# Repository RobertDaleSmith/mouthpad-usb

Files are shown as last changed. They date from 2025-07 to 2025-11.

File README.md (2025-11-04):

# MouthPad^USB

Firmware for turning the **MouthPad^** wearable into a wired USB HID device. The microcontroller sits between the tablet/PC and the MouthPad^, bridging BLE HID + NUS traffic to USB HID + CDC, without changing the MouthPad^ firmware.

## Overview

This repository contains **two platform implementations** that expose identical USB interfaces:

| Platform | MCU / SDK | Status | Documentation |
|---|---|---|---|
| **Nordic nRF52840** | NCS / Zephyr RTOS | ✅ Production | [ncs/README.md](ncs/README.md) |
| **ESP32-S3** | ESP-IDF | ✅ Feature parity | [esp/README.md](esp/README.md) |

Both firmwares expose the same HID descriptors, CDC command set, LED semantics, and bond-management behavior, so you can swap hardware without reconfiguring the host.

## Quick Start

Pick the platform that matches your hardware:

### nRF52840 (Production Hardware)

Ships on **Seeed XIAO nRF52840**. Also supports Adafruit Feather nRF52840 and Nordic/April dongles.

```bash
cd ncs
docker-compose run --rm mouthpad-build
# Flash: drag build/app/zephyr/zephyr.uf2 to bootloader drive
```

**[👉 Full NCS documentation](ncs/README.md)**

### ESP32-S3

Alternative implementation for **Seeed XIAO ESP32-S3** and LilyGo T-Dongle-S3.

```bash
cd esp
source env.sh          # Source ESP-IDF environment
make xiao              # Build for XIAO ESP32-S3
make flash             # Flash firmware
```

**[👉 Full ESP32 documentation](esp/README.md)**

## Core Features

### USB Interfaces

- **USB HID** – Mouse + consumer control (standard multi-interface HID device)
- **USB CDC Port 0** – Protobuf/text tunnel mirroring BLE NUS link
- **USB CDC Port 1** – Maintenance console (`dfu`, `clear`, `serial`) + logs

### BLE Bridge

- **BLE HID client** – Discovers and connects to MouthPad^ HID service
- **Nordic UART Service (NUS)** – Bidirectional data tunnel for configuration/telemetry
- **Bond management** – Stores pairing and auto-reconnects
- **RSSI monitoring** – Tracks connection quality

### Status Feedback

- **LED indicators** – Scanning (blink), connected (solid), activity (flicker)
- **NeoPixel support** (nRF) – Battery-level colors when available
- **Console logging** – Real-time diagnostics on CDC port 1

### Device Firmware Update (DFU)

| Platform | Method |
|---|---|
| nRF52840 (UF2) | UF2 bootloader (drag-and-drop) or type `dfu` command |
| nRF52840 (Nordic DFU) | Nordic DFU bootloader via nrfutil or nRF Connect Desktop |
| ESP32-S3 | ROM serial downloader via `dfu` command or `idf.py flash` |

## Repository Structure

```
.
├── ncs/                    # Nordic Connect SDK workspace (nRF52840)
│   ├── app/                # Application source
│   ├── Makefile            # Build helpers
│   ├── docker-compose.yml  # Containerized builds
│   └── README.md           # 👈 nRF52840 documentation
├── esp/                    # ESP-IDF workspace (ESP32-S3)
│   ├── main/               # Application source
│   ├── Makefile            # Build helpers
│   └── README.md           # 👈 ESP32-S3 documentation
├── resources/              # Additional documentation and assets
│   ├── notes/              # Technical documentation
│   └── images/             # Diagrams and photos
└── web/                    # Web-based configuration tool
```

## CDC Maintenance Commands

Both firmwares expose a maintenance console on the second CDC port:

| Command | Description |
|---|---|
| `dfu` | Reboot into bootloader (UF2 for nRF, ROM downloader for ESP32) |
| `reset` | Disconnect MouthPad^, erase BLE bonds, return to pairing mode |
| `restart` | Restart firmware (software reset) |
| `serial` | Print USB serial number |
| `version` | Display firmware version, build timestamp, and platform info |

**Port names:**
- **macOS:** `/dev/cu.usbmodem<serial>3`
- **Linux:** `/dev/ttyACM1`
- **Windows:** `COM<n>` (check Device Manager)

## Supported Hardware

### nRF52840 Boards

| Board | Status | Notes | Purchase |
|---|---|---|---|
| Seeed XIAO nRF52840 | ✅ Production | Primary shipping target ([expansion board](https://www.seeedstudio.com/Seeeduino-XIAO-Expansion-board-p-4746.html) supported) | [Seeed Studio](https://www.seeedstudio.com/Seeed-XIAO-BLE-nRF52840-p-5201.html) |
| Adafruit Feather nRF52840 Express | ✅ Production | Requires custom bootloader config | [Adafruit](https://www.adafruit.com/product/4062) |
| Nordic nRF52840 Dongle (PCA10059) | ✅ Production | Stock Nordic LED pins | [Digi-Key](https://www.digikey.com/en/products/detail/nordic-semiconductor-asa/NRF52840-DONGLE/9491124) |
| April Brothers nRF52840 Dongle (PCA10059) | ✅ Production | Non-standard LED wiring | [April Brother](https://store.aprbrother.com/product/usb-dongle-nrf52840) |
| Raytac MDBT50Q-RX Dongle | ✅ Production | UF2 bootloader, single LED | [Raytac](https://www.raytac.com/product/ins.php?index_id=89) |
| Raytac MDBT50Q-CX-40 Dongle | ✅ Production | Nordic DFU bootloader, blue+red LEDs | [Raytac](https://www.raytac.com/product/ins.php?index_id=100) |
| MakerDiary nRF52840 MDK USB Dongle | ✅ Production | RGB LED support | [MakerDiary](https://wiki.makerdiary.com/nrf52840-mdk-usb-dongle/purchase/) |

### ESP32-S3 Boards

| Board | Status | Notes | Purchase |
|---|---|---|---|
| Seeed XIAO ESP32-S3 | ✅ Supported | Mirrors nRF feature set | [Seeed Studio](https://www.seeedstudio.com/XIAO-ESP32S3-p-5627.html) |
| LilyGo T-Dongle-S3 | ✅ Supported | Alternative form factor | [Amazon](https://www.amazon.com/dp/B0BF542H39) |

## CI/CD

GitHub Actions builds firmware for all board variants on every push to `main`:

**nRF52840 builds:**
- `mouthpad^usb_seeed_xiao_nrf52840_<commit>.uf2`
- `mouthpad^usb_adafruit_feather_nrf52840_<commit>.uf2`
- `mouthpad^usb_nordic_nrf52840dongle_<commit>.uf2`
- `mouthpad^usb_aprbrother_nrf52840_<commit>.uf2`
- `mouthpad^usb_raytac_mdbt50q_rx_<commit>.uf2`
- `mouthpad^usb_raytac_mdbt50q_cx_40_<commit>.zip` (Nordic DFU)
- `mouthpad^usb_makerdiary_nrf52840mdk_<commit>.uf2`

Artifacts are available in the Actions tab for 90 days.

## Contributing

1. **Choose your platform** – Work in either `ncs/` or `esp/` directory
2. **Follow build instructions** – See platform-specific README
3. **Test on hardware** – Verify USB enumeration and BLE connection
4. **Submit PR** – Include board(s) tested in description

Both platforms should maintain behavioral parity for USB/BLE interfaces.

## Getting Help

- **Platform-specific issues:** See [ncs/README.md](ncs/README.md) or [esp/README.md](esp/README.md)
- **General questions:** Open an issue with reproduction steps
- **Build problems:** Check platform-specific troubleshooting sections

## License

MIT License – See [LICENSE](LICENSE) for details.

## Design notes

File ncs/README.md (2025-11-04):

# MouthPad^ USB – Nordic Connect SDK (nRF52840)

This directory contains the **nRF52840 firmware** for the MouthPad^ USB bridge, built with Nordic Connect SDK (NCS) and Zephyr RTOS.

## Overview

The nRF52840 firmware is the **primary production firmware** that ships on Seeed XIAO nRF52840 hardware. It bridges BLE HID + NUS traffic from the MouthPad^ wearable to USB HID + dual CDC interfaces.

**Key features:**
- BLE HID client + Nordic UART Service (NUS)
- USB HID device (mouse + consumer control)
- Dual USB CDC ports (NUS tunnel + maintenance console)
- Bond management and pairing support
- UF2 bootloader support (most boards) or Nordic DFU bootloader (CX-40)
- LED status feedback
- Console commands: `dfu`, `clear`, `serial`

## Supported Hardware

| Board | Status | Notes | Purchase |
|---|---|---|---|
| **Seeed XIAO nRF52840** (`seeed_xiao_nrf52840`) | ✅ Production | Primary shipping target ([expansion board](https://www.seeedstudio.com/Seeeduino-XIAO-Expansion-board-p-4746.html) supported) | [Seeed Studio](https://www.seeedstudio.com/Seeed-XIAO-BLE-nRF52840-p-5201.html) |
| **Adafruit Feather nRF52840** (`adafruit_feather_nrf52840`) | ✅ Production | Requires custom bootloader config | [Adafruit](https://www.adafruit.com/product/4062) |
| **Nordic nRF52840 Dongle** (`nordic_nrf52840dongle`) | ✅ Production | PCA10059 with stock Nordic LED pins | [Digi-Key](https://www.digikey.com/en/products/detail/nordic-semiconductor-asa/NRF52840-DONGLE/9491124) |
| **April Brother nRF52840 Dongle** (`aprbrother_nrf52840`) | ✅ Production | PCA10059 with non-standard LED wiring | [April Brother](https://store.aprbrother.com/product/usb-dongle-nrf52840) |
| **Raytac MDBT50Q-RX Dongle** (`raytac_mdbt50q_rx`) | ✅ Production | UF2 bootloader, single LED | [Raytac](https://www.raytac.com/product/ins.php?index_id=89) |
| **Raytac MDBT50Q-CX-40 Dongle** (`raytac_mdbt50q_cx_40`) | ✅ Production | Nordic DFU bootloader, blue+red LEDs | [Raytac](https://www.raytac.com/product/ins.php?index_id=100) |
| **MakerDiary nRF52840 MDK USB Dongle** (`makerdiary_nrf52840mdk`) | ✅ Production | Compact dongle with RGB LED | [MakerDiary](https://wiki.makerdiary.com/nrf52840-mdk-usb-dongle/purchase/) |

## Quick Start

### Docker Build (Recommended)

```bash
cd ncs
docker-compose run --rm mouthpad-build
```

The build produces `build/app/zephyr/zephyr.uf2` ready for drag-and-drop flashing.

### Native Build (with local NCS toolchain)

```bash
cd ncs

# First time: initialize workspace
make init

# Build for default board (xiao_ble)
make build

# Flash via UF2 bootloader
make flash-uf2

# Or flash via J-Link
make flash
```

**Board-specific builds:**
```bash
make build-xiao              # Seeed XIAO nRF52840
make build-feather           # Adafruit Feather nRF52840
make build-nordic-dongle     # Nordic PCA10059 (stock pins)
make build-april-dongle      # April Brother (non-standard LED)
make build-raytac-rx         # Raytac MDBT50Q-RX (UF2)
make build-raytac-cx40       # Raytac MDBT50Q-CX-40 (Nordic DFU)
make build-makerdiary-dongle # MakerDiary nRF52840 MDK (RGB LED)
```

See the [Makefile](Makefile) for all available targets.

## Workspace Structure

```
ncs/
├── app/                    # Application source and board configs
│   ├── src/                # C source files
│   ├── boards/             # Board-specific overlays
│   ├── prj.conf            # Project Kconfig
│   └── README.md           # Detailed app documentation
├── Makefile                # Build helpers
├── west.yml                # West manifest (NCS dependencies)
├── docker-compose.yml      # Containerized builds
├── Dockerfile              # Build container definition
└── bootloaders/            # Pre-built UF2 bootloaders

# Generated by `make init` or `west update`:
├── .west/                  # West workspace metadata
├── nrf/                    # NCS SDK
├── zephyr/                 # Zephyr RTOS
├── nrfxlib/                # Nordic libraries
├── modules/                # Zephyr modules
└── build/                  # Build output
```

**Note:** The generated directories (`.west/`, `nrf/`, `zephyr/`, etc.) are ignored by git and managed by the `west` tool.

## Detailed Documentation

- **[app/README.md](app/README.md)** – Application architecture, build instructions, CDC commands, LED states
- **[Makefile](Makefile)** – Build targets and helper commands
- **[docker-compose.yml](docker-compose.yml)** – Docker build configuration
- **[../resources/notes/BUILD_METHODS.md](../resources/notes/BUILD_METHODS.md)** – Alternative Zephyr build flows
- **[../resources/notes/ADAFRUIT_FEATHER_BOOTLOADER.md](../resources/notes/ADAFRUIT_FEATHER_BOOTLOADER.md)** – Feather bootloader setup

## Flashing Firmware

### UF2 Method (Recommended)

1. **Enter bootloader mode:**
   - Double-tap the reset button
   - Or type `dfu` in the maintenance console

2. **Copy firmware:**
   - Drag `build/app/zephyr/zephyr.uf2` to the bootloader drive
   - **XIAO:** `/Volumes/XIAO-SENSE` (macOS) or `/media/XIAO-SENSE` (Linux)
   - **Feather:** `/Volumes/FTHR840BOOT` (macOS) or `/media/FTHR840BOOT` (Linux)
   - **Nordic Dongle:** `/Volumes/NRF52BOOT` (macOS) or `/media/NRF52BOOT` (Linux)
   - **Raytac Dongle:** `/Volumes/MDBT50QBOOT` (macOS) or `/media/MDBT50QBOOT` (Linux)
   - **MakerDiary Dongle:** `/Volumes/UF2BOOT` (macOS) or `/media/UF2BOOT` (Linux)

3. **Automatic reboot:** Device resets automatically after copy completes

### J-Link Method

```bash
make flash
```

Requires J-Link probe connected and J-Link software installed.

### Nordic DFU Method (CX-40 only)

The Raytac CX-40 uses Nordic's DFU bootloader instead of UF2. You can flash it via command line or GUI:

**Command Line (nrfutil):**
```bash
# Build firmware first
make build-raytac-cx40

# Flash via DFU (prompts for bootloader mode)
make flash-dfu
```

**GUI (nRF Connect for Desktop - Recommended):**
1. Download [nRF Connect for Desktop](https://www.nordicsemi.com/Products/Development-tools/nRF-Connect-for-Desktop)
2. Install the "Programmer" app
3. Put device in bootloader mode (hold RESET while connecting USB)
4. Select device in nRF Connect Programmer
5. Add the `.zip` file from `build/app/zephyr/` (after running `make flash-dfu` to generate it)
6. Click "Write" to flash firmware

The device will automatically reboot with the new firmware.

## CDC Maintenance Console

The second CDC port (`/dev/cu.usbmodem<serial>3` on macOS, `/dev/ttyACM1` on Linux) provides a maintenance console with these commands:

| Command | Description |
|---|---|
| `dfu` | Reboot into UF2 bootloader |
| `clear` | Clear BLE bonds and return to pairing mode |
| `serial` | Print USB serial number used in device names |

## LED States

| State | Behavior |
|---|---|
| **Scanning** | Slow blink (seeking MouthPad^) |
| **Connected** | Solid on |
| **Activity** | Fast flicker when forwarding HID data |

NeoPixel LEDs (if available) show battery-dependent colors when connected.

## Development

### Prerequisites

- **Docker:** For containerized builds (no local toolchain needed)
- **OR Native:** NCS v3.1.0+ with Zephyr SDK and `west` on PATH

### Build System

- **`make`** – High-level wrapper around `west build`
- **`west`** – Nordic's meta-tool for managing NCS workspace
- **Docker** – Isolated builds with pre-configured toolchain

Run `make help` for all available targets.

### Debugging

**RTT Console:**
```bash
make monitor
```

Or use Segger RTT Viewer for better experience.

**GDB:**
```bash
west debug
```

Requires J-Link probe connected.

## CI/CD

GitHub Actions builds all board variants on every push:
- Seeed XIAO nRF52840
- Adafruit Feather nRF52840
- Nordic nRF52840 Dongle
- April Brother nRF52840 Dongle
- Raytac MDBT50Q-RX Dongle
- Raytac MDBT50Q-CX-40 Dongle
- MakerDiary nRF52840 MDK USB Dongle

Artifacts are uploaded as:
- `mp_usb_<board>_<commit>.uf2` for UF2 bootloader boards
- `mp_usb_<board>_<commit>.zip` for Nordic DFU bootloader boards (CX-40)

See [`.github/workflows/ci.yml`](../.github/workflows/ci.yml) for the full workflow.

## Troubleshooting

**Build fails:**
- Ensure workspace is initialized: `make init`
- Clean and rebuild: `make clean && make build`

**Flash fails:**
- Check bootloader is mounted
- Verify UF2 file exists: `ls -l build/app/zephyr/zephyr.uf2`

**Device not detected:**
- Check USB cable supports data (not just charging)
- Try different USB port
- Check system logs: `dmesg` (Linux) or Console.app (macOS)

**BLE connection fails:**
- Clear bonds: type `clear` in maintenance console
- Restart MouthPad^ wearable
- Check LED is blinking (scanning mode)

For more help, see [app/README.md](app/README.md) or open an issue.

## License

MIT License – See [../LICENSE](../LICENSE) for details.

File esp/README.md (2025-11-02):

# MouthPad^ USB – ESP32 Firmware (ESP-IDF)

ESP-IDF port of the MouthPad^ USB bridge for ESP32-S3 boards. Functionally mirrors the Zephyr/nRF
firmware with 1:1 feature parity: it scans for the MouthPad^ over BLE, relays HID and NUS traffic to USB,
exposes the same dual CDC interfaces, and offers the same maintenance commands.

## Target hardware

* **Seeed Studio XIAO ESP32-S3** – validated board with user button and LED on GPIO 21.
* **LilyGo T-Display-S3** – buildable but the board lacks a dedicated user LED; the firmware disables LED
  status on that variant.

Select the board via `make xiao` or `make lilygo` (defaults to XIAO). The Makefile injects board-specific
`sdkconfig` fragments so switching targets does not leave stale settings behind.

### External antenna setup (XIAO ESP32-S3)

For improved BLE range, use the **XIAO ESP32-S3 Sense** variant with external antenna connector:

**Required components:**
- [8dBi WiFi RP-SMA antenna (2.4GHz/5.8GHz dual band)](https://www.amazon.com/dp/B07R21LN5P) with U.FL/IPEX to RP-SMA pigtail cable
- [3D printable case for XIAO + SMA antenna](https://www.printables.com/model/1367918-xiao-esp32-sma-antenna-case)

The external antenna provides significantly better range than the PCB antenna, especially useful for extended distance operation or through obstacles.

## Features

**Core functionality (matches nRF firmware 1:1):**
* Bridges BLE HID and Nordic UART Service (NUS) traffic to USB HID + dual CDC ACM
* Automatic MouthPad^ discovery and reconnection
* LED status indicators (slow blink scanning, solid connected, fast flicker on activity)
* Maintenance console on CDC port 2 with shell commands (see below)
* Persistent BLE bonding across power cycles
* USB bcdDevice version automatically set from VERSION file

**Platform-specific features:**
* ESP-IDF toolchain and build system
* esptool-based flashing (USB serial downloader ROM)
* BLE device information query via `device` command
* GPIO 21 LED control on XIAO ESP32-S3

## Prerequisites

1. Install ESP-IDF v5.2+ (the project assumes `~/esp-idf`).
2. Run the helper to activate the correct Python environment before building:
   ```bash
   cd esp32
   . ./env.sh
   ```
3. Optional: edit `sdkconfig.board.<board>` if you need custom GPIO assignments.

## Build & flash

```bash
# Build for the XIAO ESP32-S3 target
make xiao

# Flash the firmware
make flash

# Monitor console output (auto-detects CDC port 1, exit with Ctrl+C)
make monitor

# Or use standard ESP-IDF commands
source env.sh
idf.py build flash monitor

# Clean generated build artefacts
make clean
```

**Note:** `idf.py monitor` does **not work** with TinyUSB CDC ports (it expects a traditional USB-serial chip with hardware flow control). Use `make monitor` instead, which uses `pyserial miniterm` with proper CDC support and line ending handling.

The Makefile sets `SDKCONFIG_DEFAULTS="sdkconfig.defaults;sdkconfig.board.xiao"` (or the LilyGo variant)
so the active configuration always matches the chosen board. If you switch boards, run `make clean`
before building to regenerate `sdkconfig` with the new defaults.

## CDC console commands

The TinyUSB CDC maintenance port (typically `/dev/cu.usbmodem<serial>3` on macOS) accepts these commands:

| Command | Description |
|---|---|
| `dfu` | Disconnect serial, print confirmation, and reboot into ROM serial downloader (run `idf.py flash` to reflash). |
| `reset` | Disconnect, clear all BLE bonds, and return to pairing mode. |
| `restart` | Restart firmware (software reset). |
| `serial` | Display USB serial number (derived from MAC address). |
| `version` | Display firmware build timestamp, ESP-IDF version, chip info, and VERSION file. |
| `device` | Display connected MouthPad^ device information (manufacturer, model, serial, firmware version, PnP ID). |

**Note:** The `device` command is ESP32-specific and not yet available in the nRF firmware.

## LED status

* **XIAO ESP32-S3** – GPIO 21 LED blinks while scanning, stays solid when connected, and pulses on HID
  traffic.
* **LilyGo T-Display-S3** – the firmware disables LED status because the board does not route an LED to
  a spare GPIO.

## Directory layout

```
esp32/
├── components/           # Local overrides (e.g. esp_tinyusb adjustments)
├── main/                 # Application sources
│   ├── ble_*             # BLE transport helpers
│   ├── usb_*             # TinyUSB HID/CDC glue
│   ├── leds.c            # LED state machine
│   └── main.c            # Bridge orchestration
├── Makefile              # Board-aware build/flash helpers
├── env.sh                # Helper to source ESP-IDF with the pinned Python env
├── sdkconfig.defaults    # Common ESP-IDF defaults
└── sdkconfig.board.*     # Board-specific overrides (LED GPIO/polarity)
```

## DFU workflow

1. Connect a terminal to the maintenance CDC port and type `dfu`, then close the terminal.
2. The firmware enters DFU pending state and resets into the ROM serial downloader.
3. Flash with `idf.py flash` (or `make flash`) targeting the ROM port.
4. The firmware restarts and reconnects to the MouthPad^.

## Version management

The firmware version is controlled by the `VERSION` file at the repository root. When you build:
- The VERSION file (e.g., `0.1.0`) is parsed by CMake
- USB bcdDevice descriptor is set automatically (e.g., `0.1.0` → `0x0010`)
- Version is logged at startup and visible in `version` command output

To release a new version, update the VERSION file and push to main. GitHub Actions will automatically build and create a release with firmware files named `mp_usb_{version}_{board}.bin`.

## Troubleshooting

* **LED stays off on XIAO** – ensure you ran `make clean` after switching from the LilyGo build so the
  correct `sdkconfig` was regenerated.
* **Device enumerates as plain serial** – you are in DFU mode. Reflash the application or power-cycle
the board.
* **Wrong version reported** – run `make clean` to regenerate build with current VERSION file.

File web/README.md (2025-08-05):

# MouthPad^USB Web Interface

A real-time web interface for monitoring and controlling the MouthPad^USB device.

## Features

### Real-time Monitoring
- **Touch Grid Display**: Visual representation of the 8x6 capacitive touch grid
- **Pressure Chart**: Real-time pressure data visualization
- **Serial Communication**: Direct USB serial connection to the device

### Log View Modes
- **📊 Details View**: Parsed and formatted log messages with packet analysis
- **🔍 Raw View**: Raw hexadecimal packet data for debugging

### Stream Control
- **JCP Stream**: Capacitive touch data streaming
- **IMU Stream**: Inertial measurement unit data
- **Click Stream**: Button click events
- **Power Stream**: Battery and power management data

## Usage

### Connection
1. Click "Connect Serial" to establish USB connection
2. Select the MouthPad^USB device when prompted
3. The status indicator will turn green when connected

### Log View Toggle
- Click the "📊 Details" / "🔍 Raw" button to switch between log modes
- **Details Mode**: Shows parsed packet information and sensor data
- **Raw Mode**: Shows raw hexadecimal data with packet size indicators
  - 📝 Small packets (< 32 bytes)
  - 📄 Medium packets (32-64 bytes)  
  - 📦 Large packets (> 64 bytes)

### Stream Control
- Use the "▶ StartStream" buttons to control data streams
- Active streams are highlighted in blue
- Streams automatically timeout after 15 seconds of inactivity

### Custom Commands
- Enter custom commands in the text field
- Press Enter or click "Send" to execute

### Log Management
- **Clear Log**: Clear the current log display
- **Export Log**: Download log as text file

## Technical Details

### Packet Format
The device sends framed packets with the following format:
- **New Format**: `[0xAA][0x55][LEN_H][LEN_L][DATA...][CRC_H][CRC_L]`
- **Old Format**: `[0xAA][LEN_L][LEN_H][DATA...][0x55]`

### Data Interpretation
- **JCP Packets**: 138+ bytes, capacitive touch sensor data
- **Power Packets**: 9 bytes, battery and power information
- **IMU Packets**: Inertial measurement data
- **Click Packets**: Button press events

### Browser Compatibility
- Requires Web Serial API support (Chrome, Edge, Opera)
- HTTPS required for Web Serial API access
- Local development server supported

## Development

### Local Testing
```bash
cd web_interface
python3 -m http.server 8000
# Open http://localhost:8000
```

### File Structure
- `index.html`: Main interface layout
- `script.js`: Core functionality and data processing
- `styles.css`: Dark theme styling
- `README.md`: This documentation

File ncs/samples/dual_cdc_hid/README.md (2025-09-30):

# Dual CDC + HID USB Sample

This sample demonstrates dual CDC ACM serial ports alongside USB HID using Zephyr's new USB device stack (`CONFIG_USB_DEVICE_STACK_NEXT`).

## Features

- **Dual CDC Serial Ports**
  - CDC0: Application data port
  - CDC1: Console and logging output
- **USB HID Mouse** with MouthPad descriptor
- **Custom Device Identity**
  - VID: 0x1915 (Augmental Tech)
  - PID: 0xEEEE
  - Product: "MouthPad^USB"

## Supported Boards

- **April Brothers nRF52840 Dongle** (`nrf52840dongle`)
  - UF2 bootloader without SoftDevice
  - Start address: 0x1000

- **Seeed XIAO nRF52840** (`xiao_ble`)
  - MCUboot bootloader
  - Start address: 0x27000

- **Adafruit Feather nRF52840** (`adafruit_feather_nrf52840`)
  - UF2 bootloader with SoftDevice
  - Start address: 0x26000

## Building

```bash
# April Brothers Dongle
west build -b nrf52840dongle samples/dual_cdc_hid --pristine=always

# XIAO nRF52840
west build -b xiao_ble samples/dual_cdc_hid --pristine=always

# Adafruit Feather nRF52840
west build -b adafruit_feather_nrf52840 samples/dual_cdc_hid --pristine=always
```

## Flashing

### April Brothers (nRF52840 Dongle)
```bash
nrfutil dfu usb-serial -pkg build/zephyr/app.uf2 -p /dev/tty.usbmodem*
```

### XIAO / Feather (UF2 Bootloader)
1. Double-tap reset button to enter bootloader mode
2. Copy `build/zephyr/zephyr.uf2` to the mounted drive:
   - XIAO: `/Volumes/XIAO-SENSE`
   - Feather: `/Volumes/FTHR840BOOT`

## Testing

After flashing, the device will enumerate as:
- 1x HID Mouse device
- 2x CDC ACM serial ports

Connect to CDC1 (second serial port) to view console logs showing device initialization.

Press the button to send mouse click reports via HID.

## Architecture Notes

This sample uses Zephyr's **new USB device stack** (`CONFIG_USB_DEVICE_STACK_NEXT`) which supports multiple CDC instances, unlike the legacy stack.

Each board has:
- Board-specific `.conf` file for partition configuration
- Board-specific `.overlay` file for hardware and partition layout
- Correct partition addresses for its bootloader type

## Key Configuration

- `CONFIG_USB_DEVICE_STACK_NEXT=y` - New USB stack
- `CONFIG_USBD_CDC_ACM_CLASS=y` - CDC ACM support
- `CONFIG_USBD_HID_SUPPORT=y` - HID device support
- `CONFIG_USE_DT_CODE_PARTITION=y` - Use device tree partitions (board-specific)
- `CONFIG_LOG_BACKEND_UART=n` - Prevent console recursion warnings

## Migration Reference

This sample serves as a reference for migrating the main MouthPad^USB application to support dual CDC ports alongside HID.

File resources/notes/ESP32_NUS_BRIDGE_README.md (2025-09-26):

# BLE HID + NUS Client to USB Bridge

This ESP32 firmware acts as a BLE central device that can connect to a single remote device offering both HID and NUS (Nordic UART Service) services, just like the nRF firmware implementation.

## Architecture
- **BLE Central**: Connects to a single device with both HID and NUS services
- **HID Bridge**: Forwards BLE HID reports to USB HID interface
- **NUS Bridge**: Forwards BLE NUS data to USB CDC with packet framing
- **Dual Service Support**: Both services work simultaneously on the same connection

## Configuration

The firmware supports both services by default. You can disable NUS support if not needed:

```c
// In main/app_config.h
#define ENABLE_HID_CENTRAL_MODE 1  // Always enabled
#define ENABLE_NUS_CLIENT_MODE 1   // Set to 0 to disable NUS support
```

## How It Works

1. **Device Discovery**: Scans for BLE devices with HID services
2. **Connection**: Connects to the best HID device found
3. **Service Discovery**: 
   - Discovers HID services (for HID reports)
   - Discovers NUS services (for serial data)
4. **Data Bridging**:
   - HID reports → USB HID interface
   - NUS data ↔ USB CDC interface (with packet framing)

## NUS Bridge Details

### Packet Format
```
[0xAA][0x55][Length_H][Length_L][Data...][CRC_H][CRC_L]
```

- **Start Markers**: `0xAA 0x55`
- **Length**: 2 bytes, big-endian (variable length)
- **Data**: Variable length payload (no 64-byte limit with proper framing)
- **CRC**: 2 bytes, CCITT CRC-16, big-endian

### BLE Service Details
- **Service UUID**: 6E400001-B5A3-F393-E0A9-E50E24DCCA9E
- **TX Characteristic**: Auto-detected by NOTIFY property (receives data FROM device)
- **RX Characteristic**: Auto-detected by WRITE property (sends data TO device)
- **Handle Detection**: Uses property-based discovery instead of hardcoded UUIDs

### Usage
1. Flash firmware (both HID and NUS clients are enabled by default)
2. Device scans for and connects to BLE devices with HID services
3. Once connected, it automatically discovers NUS services on the same device
4. Data flows bidirectionally:
   - HID reports: BLE → USB HID
   - NUS data: BLE ↔ USB CDC (with packet framing)

## Logging

### Separate Debug Channel
- **USB CDC**: Clean NUS bridge data only (no logs)
- **UART0**: Debug logs via TX|6 pin on XIAO expansion board servo connector
- **Connection**: Connect J-Link or USB-to-Serial to TX|6 pin at 115200 baud
- **Result**: Same clean separation as nRF RTT implementation

## Troubleshooting

### Device Not Enumerating
- Check USB cable connection
- Ensure firmware compiled and flashed successfully
- Check debug logs on TX|6 pin (servo connector) for initialization errors

### BLE Connection Issues
- Device acts as BLE central (client) for both HID and NUS services
- Make sure target device advertises HID services
- NUS service discovery happens automatically after HID connection
- Both services work on the same BLE connection
- Characteristics auto-detected by properties (NOTIFY for TX, WRITE for RX)

### NUS Data Issues
- Large packets (>64 bytes) are properly framed and sent as complete packets
- No fragmentation needed - packet framing handles variable lengths
- Check debug logs on TX|6 pin for detailed NUS communication info

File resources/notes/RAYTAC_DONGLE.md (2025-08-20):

# Raytac MDBT50Q-CX-40 with NCS 3.1.0

## Background
- The **`raytac_mdbt50q_cx_40_dongle`** board is **upstream in Zephyr**, but **not yet included in NCS 3.1.0’s Zephyr fork**.  
- NCS pins Zephyr via the `sdk-nrf/west.yml` manifest. In 3.1.0, `sdk-zephyr` is locked to a commit that predates Raytac board support.  
- The dongle ships with **Nordic Open Bootloader**, not MCUboot. That means you **cannot just flash `zephyr.hex`**; you must package the app into a DFU `.zip` with `nrfutil`.  

---

## Checking Which Zephyr You’re On
From your NCS 3.1.0 workspace:

```bash
west list sdk-zephyr -f "{name} {revision} {path}"
west manifest --freeze | grep zephyr
```

That shows the exact Zephyr commit pinned by NCS. You’ll notice it doesn’t contain the Raytac board folder.

---

## Options to Build for Raytac Dongle

### 1. Copy the Board Definition into Your App (Recommended)
- Grab the upstream `boards/raytac/mdbt50q_cx_40_dongle/` directory from Zephyr `main`.  
- Drop it into your app:  
  ```
  app_root/boards/raytac/mdbt50q_cx_40_dongle/
  ```
- Then build with:
  ```bash
  west build -b raytac_mdbt50q_cx_40_dongle/nrf52840 samples/basic/blinky
  ```

This works even if your workspace Zephyr fork doesn’t know the board.

---

### 2. Build with Upstream Zephyr (for sanity-check firmware)
- Clone upstream Zephyr and run:
  ```bash
  west build -b raytac_mdbt50q_cx_40_dongle/nrf52840 samples/basic/blinky
  ```
- Package for **Open Bootloader DFU**:
  ```bash
  nrfutil nrf5sdk-tools pkg generate \
    --hw-version 52 \
    --sd-req 0x00 \
    --application build/zephyr/zephyr.hex \
    --application-version 1 \
    blinky.zip

  nrfutil nrf5sdk-tools dfu usb-serial -pkg blinky.zip -p <serial_port>
  ```

⚠️ Do **not** flash raw HEX — Open Bootloader requires DFU packages.

---

### 3. Switch to MCUboot (One-Time Setup)
If you prefer MCUboot, you can flash MCUboot onto the dongle via Open Bootloader once, then use `west flash` or `mcumgr` for later updates. Mixing formats (e.g. signing for MCUboot but still using Open Bootloader) causes the “flashes but won’t boot” symptom.

---

## DCDC / Regulator Notes
- Old guides reference `CONFIG_SOC_DCDC_NRF52X`.  
- In Zephyr ≥ 3.0, regulators are configured via Devicetree.  
- If you need to disable the high-voltage regulator, add an overlay:

```dts
/* boards/raytac_mdbt50q_cx_40_dongle.overlay */
&regulator_hv {
    status = "disabled";
};
```

Check the board’s DTS for the actual regulator node names.

---

## Prebuilt Images (for hardware sanity checks)
- **BLE Sniffer HEX** (`sniffer_nrf52840dongle_nrf52840_4.1.1.hex`) works on the CX-40.  
- Flash it with nRF Connect Programmer to confirm USB + radio + bootloader are healthy.  
- OpenThread RCP HEX images for nRF52840 dongle also run on CX-40 (minor pin diffs for LEDs/buttons).

---

## TL;DR
1. NCS 3.1.0 doesn’t ship the Raytac board yet.  
2. Copy the board definition locally, or build with upstream Zephyr.  
3. Always package with `nrfutil` for Open Bootloader, unless you reflash MCUboot.  
4. Ignore old `CONFIG_SOC_DCDC_NRF52X` advice — use a DT overlay if needed.  
5. Use Nordic’s prebuilt sniffer HEX to quickly confirm your dongle works.

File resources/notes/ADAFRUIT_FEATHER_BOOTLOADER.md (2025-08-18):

# Adafruit Feather nRF52840 Bootloader Compatibility

This document covers the bootloader compatibility challenges and solutions for using the **Adafruit Feather nRF52840 Express** with Zephyr/nRF Connect SDK applications, specifically for the MouthPad^USB project.

## Background

The Adafruit Feather nRF52840 Express ships with a custom UF2 bootloader that differs from the standard Nordic MCUboot bootloader used in most nRF Connect SDK applications. This creates compatibility challenges when deploying Zephyr applications to the board.

## Key Issues Identified

### 1. **Bootloader Incompatibility**
- **Stock Adafruit Bootloader**: Custom UF2 bootloader optimized for Arduino/CircuitPython
- **nRF Connect SDK Default**: MCUboot with DFU support
- **Problem**: Applications built for MCUboot won't boot with Adafruit's bootloader

### 2. **Memory Layout Conflicts**
- **Adafruit Layout**: Different partition scheme optimized for their ecosystem
- **Nordic Layout**: Standard MCUboot + application + settings partitions
- **Result**: Memory conflicts and boot failures

## Solutions Implemented

### Nordic DevZone References
Key insights from Nordic Developer Zone discussions:
- [Adafruit bootloader nRF Connect Zephyr application](https://devzone.nordicsemi.com/f/nordic-q-a/89216/adafruit-bootloader-nrf-connect-zephyr-application)
- [UF2 image and bootloader compatibility](https://devzone.nordicsemi.com/f/nordic-q-a/97314/uf2-image-and-bootloader/413630)

### Solution 1: Custom Memory Layout

Created board-specific partition configuration:

**File**: `app/pm_static_adafruit_feather_nrf52840.yml`
```yaml
# Custom partition layout for Adafruit Feather bootloader compatibility
app:
  address: 0x26000  # Start after Adafruit bootloader space
  size: 0xc6000     # Adjusted for available space
  
settings_storage:
  address: 0xec000
  size: 0x8000
  
external_flash:
  address: 0xf4000
  size: 0x32000
```

### Solution 2: Board Configuration Override

**File**: `app/boards/adafruit_feather_nrf52840.conf`
```kconfig
# Disable MCUboot (incompatible with Adafruit bootloader)
CONFIG_BOOTLOADER_MCUBOOT=n

# Use single application slot (no MCUboot DFU)
CONFIG_SINGLE_APPLICATION_SLOT=y

# UF2 support for Adafruit bootloader
CONFIG_BUILD_OUTPUT_UF2=y
```

### Solution 3: Device Tree Overlay

**File**: `app/boards/adafruit_feather_nrf52840.overlay`
```dts
// Disable features not available on Feather board
&pinctrl {
    // Custom pin configurations for Feather layout
};

// Remove OLED display (not available on Feather)
/ {
    aliases {
        /delete-property/ oled-display;
    };
};
```

## Deployment Process

### For Development
1. **Build**: `west build -b adafruit_feather_nrf52840 app`
2. **Enter Bootloader**: Double-tap reset button on Feather
3. **Flash**: Copy `zephyr.uf2` to `FEATHERBOOT` drive
4. **Verify**: Board resets and runs application

### For Production
- Use GitHub Actions CI artifacts: `mouthpad^usb_adafruit_feather_nrf52840_[commit].uf2`
- Same deployment process as development

## Key Differences from XIAO Board

| Feature | XIAO nRF52840 | Adafruit Feather nRF52840 |
|---|---|---|
| **Bootloader** | MCUboot | Custom UF2 |
| **DFU Support** | Yes (MCUboot) | No |
| **Memory Layout** | Standard Nordic | Custom Adafruit |
| **Flash Method** | UF2 + DFU | UF2 only |
| **OLED Display** | Supported | Not available |
| **Pin Layout** | XIAO format | Feather format |

## Limitations

### No DFU Support
- **Impact**: Cannot use over-the-air updates
- **Workaround**: Physical access required for firmware updates
- **Alternative**: Consider MCUboot replacement (advanced)

### Single Application Slot
- **Impact**: No failsafe firmware rollback
- **Workaround**: Careful testing before deployment
- **Mitigation**: Always keep working firmware backup

### Hardware Differences
- **No OLED**: Display features disabled gracefully
- **Different Pins**: Some GPIO mappings differ from XIAO

## Troubleshooting

### Build Issues
```bash
# Clean build if switching between boards
west build -b adafruit_feather_nrf52840 app --pristine=always
```

### Boot Issues
1. **Check bootloader mode**: Double-tap reset should show `FEATHERBOOT` drive
2. **Verify UF2 file**: Ensure using Feather-specific build
3. **Memory conflicts**: Check partition manager logs

### Runtime Issues
- **I2C Problems**: Feather uses `i2c0` instead of `i2c1`
- **Display Errors**: Normal - Feather doesn't have OLED
- **Pin Mapping**: Verify GPIO assignments for Feather layout

## Future Improvements

### Potential MCUboot Migration
- Replace Adafruit bootloader with MCUboot
- Enables DFU support and dual-slot updates  
- Requires bootloader reflashing (more complex)

### Enhanced Pin Mapping
- Full GPIO compatibility layer
- Support for Feather-specific peripherals
- FeatherWing expansion compatibility

## References

1. [Nordic DevZone: Adafruit bootloader compatibility](https://devzone.nordicsemi.com/f/nordic-q-a/89216/adafruit-bootloader-nrf-connect-zephyr-application)
2. [Nordic DevZone: UF2 image and bootloader](https://devzone.nordicsemi.com/f/nordic-q-a/97314/uf2-image-and-bootloader/413630)
3. [Adafruit nRF52 Bootloader Documentation](https://github.com/adafruit/Adafruit_nRF52_Bootloader)
4. [nRF Connect SDK Partition Manager](https://developer.nordicsemi.com/nRF_Connect_SDK/doc/latest/nrf/scripts/partition_manager/partition_manager.html)

## Conclusion

The Adafruit Feather nRF52840 integration required significant bootloader compatibility work but now functions reliably with the stock Adafruit bootloader. While some advanced features like DFU are not available, the board provides an excellent alternative hardware platform for MouthPad^USB with its robust Feather ecosystem and form factor.

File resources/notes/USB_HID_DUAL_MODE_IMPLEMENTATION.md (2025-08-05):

# USB HID Dual Mode Implementation Plan

## Overview

This document outlines the implementation plan for adding **dual mode USB HID support** to the MouthPad^USB firmware, enabling both **boot protocol** (legacy compatibility) and **report protocol** (modern features) support.

## Background

### Current State
- **Report Protocol Only**: Custom mouse descriptor with enhanced features
- **Modern OS Support**: Full compatibility with Windows, macOS, Linux
- **Limited Legacy Support**: No BIOS/UEFI compatibility

### Target State
- **Dual Protocol Support**: Boot protocol + Report protocol
- **Legacy Compatibility**: BIOS/UEFI system support
- **Automatic Selection**: OS chooses optimal protocol
- **Enhanced Features**: Maintain all current functionality

## Implementation Plan

### Phase 1: Core Infrastructure

#### 1.1 Add Boot Protocol Descriptor
```c
// Standard boot mouse descriptor for legacy compatibility
static const uint8_t hid_boot_mouse_desc[] = {
    0x05, 0x01,        // Usage Page (Generic Desktop)
    0x09, 0x02,        // Usage (Mouse)
    0xA1, 0x01,        // Collection (Application)
    0x09, 0x01,        // Usage (Pointer)
    0xA1, 0x00,        // Collection (Physical)
    0x05, 0x09,        // Usage Page (Button)
    0x19, 0x01,        // Usage Minimum (Button 1)
    0x29, 0x03,        // Usage Maximum (Button 3)
    0x15, 0x00,        // Logical Minimum (0)
    0x25, 0x01,        // Logical Maximum (1)
    0x95, 0x03,        // Report Count (3)
    0x75, 0x01,        // Report Size (1)
    0x81, 0x02,        // Input (Data, Variable, Absolute)
    0x95, 0x01,        // Report Count (1)
    0x75, 0x05,        // Report Size (5)
    0x81, 0x01,        // Input (Constant)
    0x05, 0x01,        // Usage Page (Generic Desktop)
    0x09, 0x30,        // Usage (X)
    0x09, 0x31,        // Usage (Y)
    0x09, 0x38,        // Usage (Wheel)
    0x15, 0x81,        // Logical Minimum (-127)
    0x25, 0x7F,        // Logical Maximum (127)
    0x75, 0x08,        // Report Size (8)
    0x95, 0x03,        // Report Count (3)
    0x81, 0x06,        // Input (Data, Variable, Relative)
    0xC0,              // End Collection
    0xC0               // End Collection
};
```

#### 1.2 Add Protocol State Management
```c
// Protocol state tracking
static enum {
    USB_HID_PROTOCOL_BOOT,
    USB_HID_PROTOCOL_REPORT
} current_protocol = USB_HID_PROTOCOL_REPORT;

// Configuration option
CONFIG_USB_HID_DUAL_MODE=y
```

#### 1.3 Dynamic Descriptor Selection
```c
// Function to get appropriate descriptor based on protocol
static const uint8_t *get_hid_descriptor(void)
{
    if (current_protocol == USB_HID_PROTOCOL_BOOT) {
        return hid_boot_mouse_desc;
    } else {
        return hid_report_desc;  // Current custom descriptor
    }
}
```

### Phase 2: Protocol Switching Support

#### 2.1 USB HID Protocol Callbacks
```c
// Protocol switching callback
static int usb_hid_set_protocol_cb(const struct device *dev, uint8_t protocol)
{
    if (protocol == 0) {  // Boot protocol
        current_protocol = USB_HID_PROTOCOL_BOOT;
        LOG_INF("Switched to BOOT protocol");
    } else if (protocol == 1) {  // Report protocol
        current_protocol = USB_HID_PROTOCOL_REPORT;
        LOG_INF("Switched to REPORT protocol");
    }
    return 0;
}

// Protocol query callback
static int usb_hid_get_protocol_cb(const struct device *dev, uint8_t *protocol)
{
    *protocol = (current_protocol == USB_HID_PROTOCOL_BOOT) ? 0 : 1;
    return 0;
}
```

#### 2.2 Enhanced HID Operations Structure
```c
static const struct hid_ops ops = {
    .int_in_ready = int_in_ready_cb,
    .set_protocol = usb_hid_set_protocol_cb,
    .get_protocol = usb_hid_get_protocol_cb,
};
```

### Phase 3: Report Format Conversion

#### 3.1 Boot Protocol Report Format
```c
// Standard boot mouse report format
struct boot_mouse_report {
    uint8_t buttons;    // 3 bits for buttons, 5 bits reserved
    int8_t x;          // X movement (-127 to +127)
    int8_t y;          // Y movement (-127 to +127)
    int8_t wheel;      // Wheel movement (-127 to +127)
};
```

#### 3.2 Report Conversion Function
```c
// Convert custom reports to boot format
static void convert_to_boot_format(const uint8_t *custom_report, uint8_t *boot_report)
{
    if (current_protocol == USB_HID_PROTOCOL_BOOT) {
        // Convert Report ID 1 (buttons + wheel) to boot format
        boot_report[0] = custom_report[1] & 0x07;  // Buttons (3 bits)
        boot_report[1] = custom_report[2];          // X movement
        boot_report[2] = custom_report[3];          // Y movement  
        boot_report[3] = custom_report[1] >> 3;    // Wheel
    } else {
        // Use custom format directly
        memcpy(boot_report, custom_report, sizeof(custom_report));
    }
}
```

#### 3.3 Enhanced Report Sending
```c
// Modified report sending function
static int send_hid_report(const uint8_t *data, uint16_t len)
{
    uint8_t converted_report[4];
    
    if (current_protocol == USB_HID_PROTOCOL_BOOT) {
        convert_to_boot_format(data, converted_report);
        return hid_int_ep_write(hid_dev, converted_report, 4, NULL);
    } else {
        return hid_int_ep_write(hid_dev, data, len, NULL);
    }
}
```

### Phase 4: Configuration and Testing

#### 4.1 Configuration Options
```c
# Add to prj.conf
CONFIG_USB_HID_DUAL_MODE=y
CONFIG_USB_HID_BOOT_PROTOCOL=y
CONFIG_USB_HID_REPORT_PROTOCOL=y
CONFIG_USB_HID_AUTO_PROTOCOL_SELECTION=y
```

#### 4.2 Runtime Protocol Selection
```c
// API for runtime protocol switching
int usb_hid_set_protocol(enum usb_hid_protocol protocol);
int usb_hid_get_protocol(enum usb_hid_protocol *protocol);
```

#### 4.3 Testing Strategy
1. **Legacy System Testing**: BIOS/UEFI compatibility
2. **Modern OS Testing**: Windows, macOS, Linux
3. **Protocol Switching**: Automatic and manual switching
4. **Feature Testing**: Enhanced features in report mode

## Benefits

### Legacy Compatibility
- ✅ **BIOS/UEFI Support**: Boot protocol for legacy systems
- ✅ **Older OS Support**: Windows 98/XP compatibility
- ✅ **Embedded Systems**: Industrial/medical device compatibility

### Modern Features
- ✅ **Enhanced Functionality**: Media keys, extra buttons
- ✅ **Custom Reports**: Flexible data formats
- ✅ **Advanced Features**: High-resolution movement, pressure sensitivity

### Automatic Selection
- ✅ **OS Detection**: Automatic protocol selection
- ✅ **Fallback Support**: Boot protocol if report fails
- ✅ **Optimal Performance**: Best protocol for each system

## Implementation Timeline

### Week 1: Core Infrastructure
- [ ] Add boot protocol descriptor
- [ ] Implement protocol state management
- [ ] Add dynamic descriptor selection

### Week 2: Protocol Switching
- [ ] Implement protocol switching callbacks
- [ ] Add enhanced HID operations
- [ ] Test protocol switching

### Week 3: Report Conversion
- [ ] Implement report format conversion
- [ ] Add enhanced report sending
- [ ] Test report conversion

### Week 4: Testing and Polish
- [ ] Comprehensive testing
- [ ] Documentation updates
- [ ] Performance optimization

## Technical Considerations

### Memory Usage
- **Boot Descriptor**: ~50 bytes additional
- **Protocol State**: 1 byte additional
- **Conversion Buffer**: 4 bytes additional
- **Total Overhead**: ~55 bytes

### Performance Impact
- **Protocol Switching**: Minimal overhead
- **Report Conversion**: <1μs per report
- **Memory Usage**: Negligible increase

### Compatibility Matrix

| System Type | Boot Protocol | Report Protocol | Auto Selection |
|---|---|---|---|
| **BIOS/UEFI** | ✅ Yes | ❌ No | ✅ Boot |
| **Windows 98/XP** | ✅ Yes | ❌ No | ✅ Boot |
| **Windows 7+** | ✅ Yes | ✅ Yes | ✅ Report |
| **macOS** | ✅ Yes | ✅ Yes | ✅ Report |
| **Linux** | ✅ Yes | ✅ Yes | ✅ Report |
| **Embedded** | ✅ Yes | ❌ No | ✅ Boot |

## Future Enhancements

### Keyboard Support
- Add boot keyboard descriptor
- Implement keyboard report conversion
- Support for legacy keyboard compatibility

### Enhanced Features
- Pressure sensitivity in report mode
- High-resolution movement
- Custom button mappings
- Macro support

### Advanced Protocol Selection
- Machine learning for protocol optimization
- User preference storage
- Performance monitoring and adaptation

## Conclusion

This dual mode implementation will provide **maximum compatibility** while maintaining **enhanced functionality**, making the MouthPad^USB device suitable for both **legacy systems** and **modern applications**.

The implementation is **modular** and **backward compatible**, ensuring that existing functionality is preserved while adding new capabilities for broader system support.

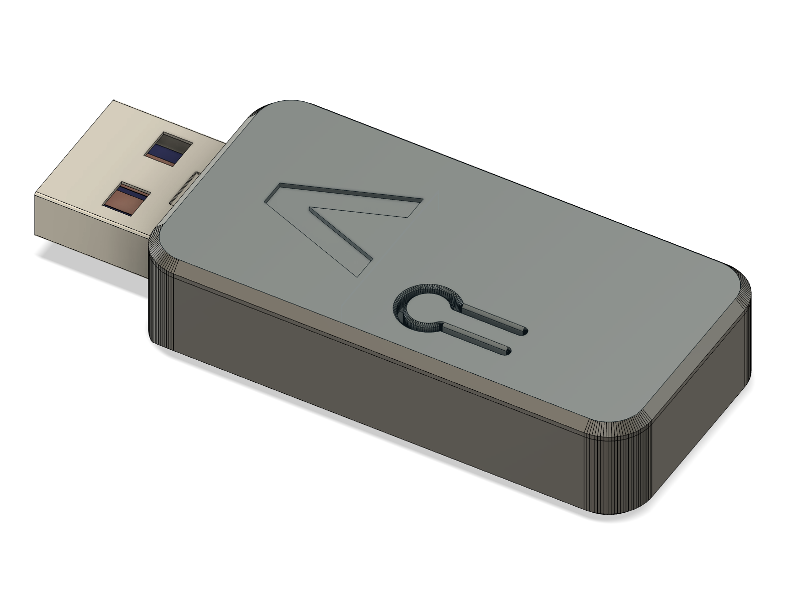
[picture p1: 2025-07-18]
resources/images/mouthpad_usb_3d_full.png

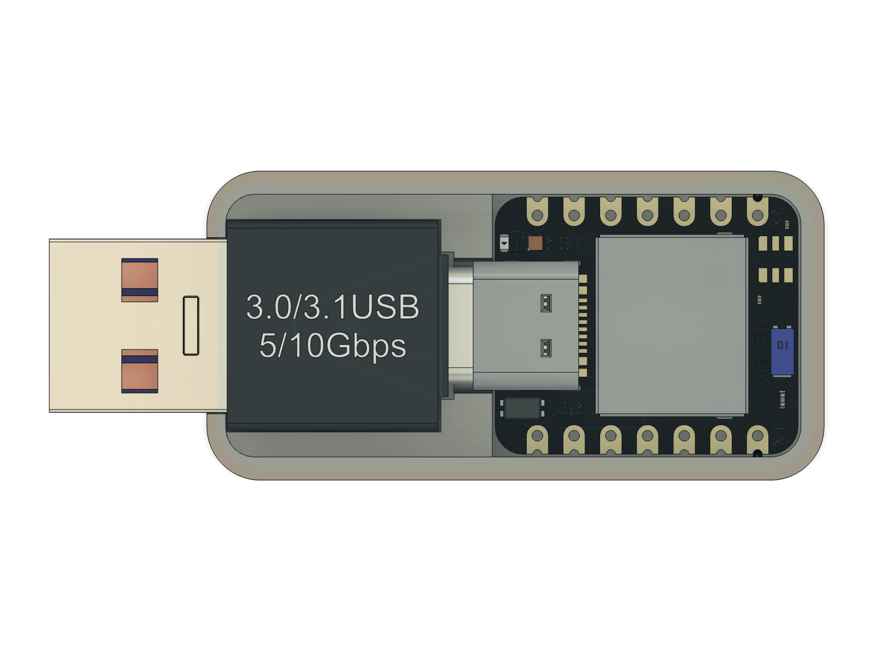
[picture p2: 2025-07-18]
resources/images/mouthpad_usb_3d_open.png

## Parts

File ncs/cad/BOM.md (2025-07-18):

# MouthPad^ USB 

## BOM

### Parts
- Seeed Studio XIAO nRF52840 [[Amazon](https://www.amazon.com/Seeed-Studio-XIAO-nRF52840-Microcontroller/dp/B09T9VVQG7)]
- USB-C to USB-A Adapter [[Amazon](https://www.amazon.com/dp/B0BNDQZCWG)]

### 3D Print Files

- `mouthpad_usb_bottom.stl`: main enclosure everything snaps into
- `mouthpad_usb_top.stl`: snap on lid with easy access reset button

### Assemble

Connect *USB-C to USB-A* adapter to *Seeed* module. Next place the two into the **bottom** enclosure shell. Parts should fit snuggly. 🤗


Then finally snap on the **top** half of the 3d printed enclosure shell. ^👅


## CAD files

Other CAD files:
ncs/cad/mouthpad_usb.step
ncs/cad/mouthpad_usb_bottom.stl
ncs/cad/mouthpad_usb_top.stl
ncs/cad/mouthpad_usb.f3d

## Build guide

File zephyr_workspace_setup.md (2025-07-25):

# Zephyr Workspace Setup with Custom Project in `/projects`

This guide walks through setting up an nRF Connect SDK (Zephyr) workspace and adding your own application inside a `projects/` folder.

---

## 1. Setup Zephyr Workspace

```bash
# Clone manifest repo
west init -m https://github.com/nrfconnect/sdk-nrf --mr v2.6.0 zephyr_workspace
cd zephyr_workspace

# Pull in all modules
west update

# Set up environment variables
west zephyr-export

# Optional: Install Python requirements
pip install -r zephyr/scripts/requirements.txt
```

---

## 2. Directory Structure

```
zephyr_workspace/
├── .west/
├── build/                    # (generated by west)
├── nrf/                      # nRF Connect SDK content
├── zephyr/                   # Zephyr RTOS core
├── modules/                  # Additional modules
├── west.yml
└── projects/                 # <-- Your custom apps go here
    └── mouthpad_usb/
        ├── src/
        │   ├── main.c
        │   ├── usb.c
        │   └── usb.h
        ├── prj.conf
        └── CMakeLists.txt
```

---

## 3. Project Files

### `CMakeLists.txt`

```cmake
cmake_minimum_required(VERSION 3.20.0)
find_package(Zephyr REQUIRED HINTS $ENV{ZEPHYR_BASE})
project(mouthpad_usb)

target_sources(app PRIVATE src/main.c src/usb.c)
```

### `prj.conf`

```ini
CONFIG_MAIN_STACK_SIZE=2048

# USB
CONFIG_USB_DEVICE_STACK=y
CONFIG_USB_DEVICE_PID=0x1234
CONFIG_USB_DEVICE_VID=0xCafe
CONFIG_USB_HID=y
CONFIG_USB_HID_MOUSE=y

# BLE Central (optional)
CONFIG_BT=y
CONFIG_BT_CENTRAL=y
CONFIG_BT_OBSERVER=y
CONFIG_BT_GATT_CLIENT=y
```

---

## 4. Build the Project

From the workspace root:

```bash
west build -b xiao_ble --pristine=always projects/mouthpad_usb
```

If renamed:

```bash
west build -b xiao_ble --pristine=always projects/my_new_app
```

---

## 5. Flash the Project

```bash
west flash --runner jlink --build-dir build
```

---

## 6. Debugging Tips

- If build loops endlessly, it may be a `Kconfig` or `sysbuild` issue.
- Disable sysbuild if needed:

```bash
west build -b xiao_ble --pristine=always --no-sysbuild projects/mouthpad_usb
```

- Use menuconfig to explore or tweak options:

```bash
west build -t menuconfig
```

---

Let me know if you'd like a ready-to-use example workspace template!

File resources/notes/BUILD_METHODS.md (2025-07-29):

# MouthPad USB Build Methods

This document describes the four different ways to build the MouthPad USB firmware.

## Method 1: Zephyr Workspace (Traditional NCS)

**Best for:** Development, debugging, and when you need full NCS workspace access.

### Setup:
```bash
# Create a Zephyr workspace
mkdir ~/zephyr_workspace
cd ~/zephyr_workspace

# Initialize with NCS
west init -m https://github.com/nrfconnect/sdk-nrf.git --mr main
west update

# Copy the mouthpad_usb app into the workspace
cp -r /path/to/mouthpad_usb/app projects/mouthpad_usb
```

### Build:
```bash
# From the workspace root
west build -b xiao_ble projects/mouthpad_usb --pristine=always
```

### Flash:
```bash
west flash --runner jlink --build-dir build/mouthpad_usb
```

## Method 2: Standalone Workspace (Make Commands)

**Best for:** Quick builds and CI/CD integration.

### Setup:
The project includes a `Makefile` with convenient commands:

```bash
# Build for xiao_ble
make build

# Flash the firmware
make flash

# Open serial monitor
make monitor
```

### Requirements:
- Zephyr SDK installed locally
- `west` tool installed
- Proper environment variables set

## Method 3: VS Code NRF Connect Extension

**Best for:** Visual development with integrated debugging.

### Setup:
1. Install the "NRF Connect for VS Code" extension
2. Open the project folder in VS Code
3. Use Command Palette: `NRF Connect: Add Existing Project`
4. Select the `/app` directory
5. Create a build configuration:
   - Board: `xiao_ble`
   - Build directory: `build`
   - Configuration: Use project's `prj.conf`

### Build:
- Use the VS Code build panel
- Or Command Palette: `NRF Connect: Build Project`

## Method 4: Docker (Recommended)

**Best for:** Consistent builds, CI/CD, and avoiding local environment setup.

### Prerequisites:
- Docker and Docker Compose installed
- No local Zephyr SDK required

### Quick Build:
```bash
# Build all boards (currently only xiao_ble active)
docker-compose run --rm mouthpad-build
```

### Interactive Development:
```bash
# Start development container
docker-compose run --rm mouthpad-dev

# Inside container:
cd /zephyr_workspace
west build -b xiao_ble app --pristine=always
```

### Build Artifacts:
- UF2 files are automatically generated with date stamps
- Located in `./build/` directory
- Named: `mouthpad_usb_xiao_ble_YYYYMMDD.uf2`

## Build Output Comparison

| Method | Speed | Setup Complexity | Debugging | CI/CD Ready |
|---|---|---|---|---|
| Zephyr Workspace | Medium | High | Excellent | Good |
| Make Commands | Fast | Medium | Good | Excellent |
| VS Code Extension | Medium | Low | Excellent | Poor |
| Docker | Fast | Low | Good | Excellent |

## Troubleshooting

### Docker Build Issues:
```bash
# Clear all caches
docker-compose down -v
docker system prune -f

# Rebuild from scratch
docker-compose run --rm mouthpad-build
```

### Local Build Issues:
```bash
# Clean build directory
rm -rf build/

# Update west workspace
west update

# Rebuild
west build -b xiao_ble app --pristine=always
```

### VS Code Extension Issues:
- Ensure the correct board is selected
- Check that the `/app` directory is properly recognized
- Verify `prj.conf` is in the app directory

## Environment Variables

For local builds, ensure these are set:
```bash
export ZEPHYR_SDK_INSTALL_DIR=/path/to/zephyr-sdk
export ZEPHYR_TOOLCHAIN_VARIANT=zephyr
export PATH=$ZEPHYR_SDK_INSTALL_DIR/sysroots/x86_64-pokysdk-linux/usr/bin:$PATH
```

## Board Support

Currently supported boards:
- `xiao_ble` (primary target)
- `nrf52840dongle` (commented out due to build issues)
- `nrf52840dk/nrf52840` (commented out due to build issues)

To enable additional boards, uncomment the relevant sections in `docker-compose.yml`.

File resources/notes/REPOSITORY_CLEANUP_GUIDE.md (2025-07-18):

# Repository Cleanup Guide

## Current State
Your repository is **3.8GB** with **80,258 files** - this is massive! Here's what's taking up space:

### Large Directories (can be removed):
- **modules/**: 1.9GB - Zephyr modules and libraries
- **zephyr/**: 921MB - Zephyr RTOS source code
- **nrf/**: 388MB - Nordic Connect SDK
- **build/**: 46MB - Build artifacts
- **bootloader/**: 16MB - MCUboot bootloader
- **.west/**: 4KB - West workspace

### Your Actual Project (keep these):
- **src/**: 100KB - Your source code
- **boards/**: 0B - Custom board definitions
- **sdk_config/**: 4KB - SDK configuration
- **scripts/**: ~20KB - Custom build/flash scripts
- **Config files**: ~20KB - Project configuration
- **Documentation**: ~30KB - README and guides

## What Can Be Safely Removed

### 1. Build Artifacts (regenerated automatically)
- `build/` - All build outputs
- `*.elf`, `*.bin`, `*.hex`, `*.uf2` - Compiled binaries
- `CMakeCache.txt`, `CMakeFiles/` - CMake cache
- `.ninja_deps`, `build.ninja` - Ninja build files

### 2. Dependencies (managed by West)
- `zephyr/` - Zephyr RTOS (pulled by `west update`)
- `nrf/` - Nordic Connect SDK (pulled by `west update`)
- `nrfxlib/` - Nordic libraries (pulled by `west update`)
- `modules/` - Zephyr modules (pulled by `west update`)
- `bootloader/` - MCUboot (pulled by `west update`)
- `tools/` - Build tools (pulled by `west update`)
- `.west/` - West workspace (regenerated by `west init`)

### 3. Test Files (not needed for main project)
- `test/` - Test files and frameworks

### 4. IDE and System Files
- `.vscode/` - VS Code settings
- `.DS_Store` - macOS system files
- `*.backup` - Backup files

## How to Clean Up

### Option 1: Use the cleanup script (recommended)
```bash
./scripts/cleanup.sh
```

### Option 2: Manual cleanup
```bash
# Remove build artifacts
rm -rf build/

# Remove dependencies (will be restored by west)
rm -rf zephyr/ nrf/ nrfxlib/ modules/ bootloader/ tools/ test/

# Remove workspace
rm -rf .west/

# Remove system files
rm -f .DS_Store
rm -f prj.conf.backup
```

## After Cleanup

### Restore Dependencies
```bash
# Initialize west workspace
west init -l .

# Update dependencies
west update
```

### Build Project
```bash
# Build the project
make build
```

## Expected Results

### Before Cleanup:
- Repository size: **3.8GB**
- File count: **80,258 files**

### After Cleanup:
- Repository size: **~200KB** (99.995% reduction!)
- File count: **~50 files**

## Git Management

### Add .gitignore
The `.gitignore` file I created will prevent these files from being tracked in the future.

### Commit Strategy
1. **Keep in Git**: Your source code, configuration, and custom scripts
2. **Ignore**: Build artifacts and dependencies (managed by West)

### For New Developers
New developers just need to:
```bash
git clone <your-repo>
west init -l .
west update
make build
```

## Benefits

1. **Massive size reduction**: 3.8GB → ~200KB
2. **Faster cloning**: New developers get only essential files
3. **Cleaner history**: No build artifacts in Git history
4. **Easier maintenance**: Dependencies managed by West
5. **Better collaboration**: Focus on your code, not dependencies

## Important Notes

- **Dependencies are versioned**: `west.yml` specifies exact versions
- **Reproducible builds**: `west update` restores exact same versions
- **No functionality loss**: All build capabilities remain intact
- **Standard practice**: This is how Zephyr projects should be managed

## Troubleshooting

If something breaks after cleanup:
```bash
# Full restore
west init -l .
west update
make clean
make build
```

The cleanup is completely safe and reversible!

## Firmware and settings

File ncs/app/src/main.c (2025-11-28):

/*
 * Copyright (c) 2025 Robert Dale Smith
 * Copyright (c) 2025 Augmental Tech
 *
 * SPDX-License-Identifier: Apache-2.0
 */

/** @file
 *  @brief MouthPad USB Bridge - Main Application
 */

#include <zephyr/logging/log.h>
#include <zephyr/shell/shell.h>
#include <zephyr/drivers/hwinfo.h>
#include <string.h>
#include <nrf.h>

#include "usb_cdc.h"
#include "usb_hid.h"
#include "ble_transport.h"
#include "ble_central.h"
#include "ble_bas.h"
#include "ble_dis.h"
#include "oled_display.h"
#include "buzzer.h"
#include "leds.h"
#include "button.h"
#include "MouthpadRelay.pb.h"
#include "pb_decode.h"
#include "pb_encode.h"

#define LOG_MODULE_NAME main
LOG_MODULE_REGISTER(LOG_MODULE_NAME);

static void clear_ble_pairings(void)
{
	if (ble_transport_is_connected()) {
		LOG_INF("Disconnecting current BLE connection before clearing bonds...");
		ble_transport_disconnect();
		/* Wait for disconnect to complete before clearing bonds */
		k_sleep(K_MSEC(500));
	}

	ble_transport_clear_bonds();

	/* Clear saved DIS info since bonded device is being removed */
	extern void ble_dis_clear_saved(void);
	ble_dis_clear_saved();

	LOG_INF("BLE bonds cleared - ready for new pairing");
}

/* Shell command: Enter DFU bootloader mode */
static int cmd_dfu(const struct shell *sh, size_t argc, char **argv)
{
	ARG_UNUSED(argc);
	ARG_UNUSED(argv);

	shell_print(sh, "Entering DFU bootloader mode...");
	k_sleep(K_MSEC(100)); /* Brief delay for message to be sent */

	/* Set GPREGRET magic value for UF2 bootloader */
	NRF_POWER->GPREGRET = 0x57;

	/* Perform system reset */
	NVIC_SystemReset();

	return 0;
}

/* Shell command: Display USB serial number (device ID) */
static int cmd_serial(const struct shell *sh, size_t argc, char **argv)
{
	ARG_UNUSED(argc);
	ARG_UNUSED(argv);

	uint8_t hwid[8];
	ssize_t hwid_len = hwinfo_get_device_id(hwid, sizeof(hwid));

	if (hwid_len > 0) {
		shell_print(sh, "USB Serial Number: %02X%02X%02X%02X%02X%02X%02X%02X",
			    hwid[0], hwid[1], hwid[2], hwid[3],
			    hwid[4], hwid[5], hwid[6], hwid[7]);
		shell_print(sh, "Port should show as: usbmodem%02X%02X%02X%02X%02X%02X%02X%02X<N>",
			    hwid[0], hwid[1], hwid[2], hwid[3],
			    hwid[4], hwid[5], hwid[6], hwid[7]);
	} else {
		shell_error(sh, "Failed to read device ID: %d", hwid_len);
	}

	return 0;
}

/* Shell command: Reset BLE bonds and pairing state */
static int cmd_reset(const struct shell *sh, size_t argc, char **argv)
{
	ARG_UNUSED(argc);
	ARG_UNUSED(argv);

	shell_print(sh, "Resetting stored BLE bonds and pairing state...");
	clear_ble_pairings();
	shell_print(sh, "Bonds cleared. Put MouthPad into pairing mode to reconnect.");

	return 0;
}

/* Shell command: Restart firmware */
static int cmd_restart(const struct shell *sh, size_t argc, char **argv)
{
	ARG_UNUSED(argc);
	ARG_UNUSED(argv);

	shell_print(sh, "Restarting firmware...");
	k_sleep(K_MSEC(100));  // Give log time to flush

	/* Perform system reset */
	NVIC_SystemReset();

	return 0;
}

/* Shell command: Display firmware version information */
static int cmd_version(const struct shell *sh, size_t argc, char **argv)
{
	ARG_UNUSED(argc);
	ARG_UNUSED(argv);

	shell_print(sh, "=== MouthPad^USB (nRF52) ===");
	shell_print(sh, "Built: %s %s", __DATE__, __TIME__);
#ifdef BUILD_VERSION
	shell_print(sh, "App Version: %s", STRINGIFY(BUILD_VERSION));
#endif

	return 0;
}

/* Shell command: Display bonded devices */
static int cmd_bonds(const struct shell *sh, size_t argc, char **argv)
{
	ARG_UNUSED(argc);
	ARG_UNUSED(argv);

	struct bonded_device bonds[MAX_BONDED_DEVICES];
	int count = ble_central_get_bonded_devices(bonds, MAX_BONDED_DEVICES);

	if (count < 0) {
		shell_error(sh, "Failed to get bonded devices (err %d)", count);
		return count;
	}

	if (count == 0) {
		shell_print(sh, "No bonded devices");
	} else {
		shell_print(sh, "=== Bonded Devices (%d/%d) ===", count, MAX_BONDED_DEVICES);
		for (int i = 0; i < MAX_BONDED_DEVICES; i++) {
			if (bonds[i].is_valid) {
				char addr_str[BT_ADDR_LE_STR_LEN];
				bt_addr_le_to_str(&bonds[i].addr, addr_str, sizeof(addr_str));

				if (bonds[i].name[0] != '\0') {
					shell_print(sh, "  [%d] %s - %s", i, bonds[i].name, addr_str);
				} else {
					shell_print(sh, "  [%d] (no name) - %s", i, addr_str);
				}
			}
		}
		shell_print(sh, "===========================");
	}

	return 0;
}

/* Shell command: Clear cached firmware versions */
static int cmd_clear_fw_cache(const struct shell *sh, size_t argc, char **argv)
{
	ARG_UNUSED(argc);
	ARG_UNUSED(argv);

	shell_print(sh, "Clearing cached firmware versions for all bonds...");
	extern void ble_dis_clear_all_cached_firmware(void);
	ble_dis_clear_all_cached_firmware();
	shell_print(sh, "Done. Firmware versions will be re-read on next connection.");

	return 0;
}

SHELL_CMD_REGISTER(bonds, NULL, "Display bonded devices", cmd_bonds);
SHELL_CMD_REGISTER(clearfwcache, NULL, "Clear cached firmware versions", cmd_clear_fw_cache);
SHELL_CMD_REGISTER(dfu, NULL, "Enter DFU bootloader mode", cmd_dfu);
SHELL_CMD_REGISTER(reset, NULL, "Reset stored BLE bonds", cmd_reset);
SHELL_CMD_REGISTER(restart, NULL, "Restart firmware", cmd_restart);
SHELL_CMD_REGISTER(serial, NULL, "Display USB serial number", cmd_serial);
SHELL_CMD_REGISTER(version, NULL, "Display firmware version", cmd_version);

/* Battery color indication mode - automatically set based on LED hardware */
/* GPIO LEDs use discrete mode, NeoPixel uses gradient mode */

/* Button event callback function */
static void button_event_callback(button_event_t event)
{
	switch (event) {
	case BUTTON_EVENT_CLICK:
		LOG_INF("=== BUTTON CLICK ===");
		/* Reserved for future functionality */
		break;

	case BUTTON_EVENT_DOUBLE_CLICK:
		LOG_INF("=== BUTTON DOUBLE CLICK ===");
		/* Reserved for future functionality */
		break;

	case BUTTON_EVENT_HOLD:
		LOG_INF("=== BUTTON HOLD - CLEARING BLE BONDS ===");
		/* Clear BLE bonds and reset for new pairing */
		clear_ble_pairings();
		break;
		
	default:
		break;
	}
}

/* USB HID callback function */
static void usb_hid_data_callback(const uint8_t *data, uint16_t len)
{
	// This callback is for USB HID data going TO USB (BLE->USB bridge)
	// Button detection is now handled in BLE HID layer where we have Report ID context
	
	// Bridge USB HID data to BLE HID
	if (ble_transport_is_hid_ready()) {
		LOG_DBG("BLE HID is ready, sending %d bytes", len);
		int err = ble_transport_send_hid_data(data, len);
		if (err) {
			LOG_ERR("USB HID→BLE HID FAILED (err %d)", err);
		} else {
			LOG_DBG("USB HID data sent to BLE HID successfully");
		}
	} else {
		LOG_DBG("HID client not ready - waiting for service discovery");
	}
}

/* nanopb string encoding callback for device info strings */
static bool encode_string_callback(pb_ostream_t *stream, const pb_field_t *field, void * const *arg)
{
	const char *str = (const char *)(*arg);

	if (!str || str[0] == '\0') {
		return true;  /* Empty string, nothing to encode */
	}

	if (!pb_encode_tag_for_field(stream, field)) {
		return false;
	}

	return pb_encode_string(stream, (const uint8_t *)str, strlen(str));
}

int usb_cdc_send_proto_message(mouthware_message_RelayToAppMessage message)
{
	uint8_t dataPacket[1024];
	pb_ostream_t stream = pb_ostream_from_buffer(dataPacket, sizeof(dataPacket));
	if (!pb_encode(&stream, mouthware_message_RelayToAppMessage_fields, &message)) {
		LOG_ERR("Encoding failed: %s\n", PB_GET_ERROR(&stream));
		return -1;
	}
	return usb_cdc_send_data(dataPacket, stream.bytes_written);
}

int mouthpad_nus_data_received_callback(const uint8_t *data, uint16_t len)
{
	/* Forward data from MouthPad (BLE NUS) to USB CDC0 - minimal logging to keep CDC0 clean */
	LOG_DBG("NUS→CDC: %d bytes", len);

	// take binary data received via BLE, wrap it in a RelayToAppMessage and send it to the USB CDC
	mouthware_message_RelayToAppMessage message = mouthware_message_RelayToAppMessage_init_zero;
	message.which_message_body = mouthware_message_RelayToAppMessage_pass_through_to_app_tag;
	message.message_body.pass_through_to_app.data.size = len;
	memcpy(message.message_body.pass_through_to_app.data.bytes, data, len);

	return usb_cdc_send_proto_message_async(message);
}


int main(void)
{
	int err;

	LOG_INF("=== MouthPad^USB Starting === Built: %s %s", __DATE__, __TIME__);

	/* Initialize USB device stack (HID + CDC) */
	LOG_INF("Initializing USB device stack...");
	err = usb_init();
	if (err != 0) {
		LOG_ERR("usb_init failed (err %d)", err);
		return 0;
	}
	LOG_INF("USB device stack initialized successfully");

	/* Initialize USB CDC (get CDC0 device reference) */
	LOG_INF("Initializing USB CDC...");
	err = usb_cdc_init();
	if (err != 0) {
		LOG_ERR("usb_cdc_init failed (err %d)", err);
		return 0;
	}
	LOG_INF("USB CDC initialized successfully");

	/* Debug: Test HWINFO device ID reading */
	uint8_t hwid[8];
	ssize_t hwid_len = hwinfo_get_device_id(hwid, sizeof(hwid));
	if (hwid_len > 0) {
		LOG_INF("USB Serial Number: %02X%02X%02X%02X%02X%02X%02X%02X",
			hwid[0], hwid[1], hwid[2], hwid[3],
			hwid[4], hwid[5], hwid[6], hwid[7]);
	} else {
		LOG_ERR("HWINFO get_device_id failed: %d", hwid_len);
	}

	/* Initialize OLED Display */
	err = oled_display_init();
	if (err != 0) {
		LOG_WRN("oled_display_init failed (err %d) - continuing without display", err);
		/* Continue without display - it's not critical for core functionality */
	} else {
		/* Show splash screen with Augmental logo */
		oled_display_splash_screen(2000);  /* Show logo for 2 seconds */
	}

	/* Initialize Passive Buzzer */
	err = buzzer_init();
	if (err != 0) {
		LOG_WRN("buzzer_init failed (err %d) - continuing without buzzer", err);
		/* Continue without buzzer - it's not critical for core functionality */
	} else if (buzzer_is_available()) {
		LOG_INF("Passive Buzzer initialized successfully");
	}

	/* Initialize BLE Transport */
	LOG_INF("Initializing BLE Transport...");
	err = ble_transport_init();
	if (err != 0) {
		LOG_ERR("ble_transport_init failed (err %d)", err);
		return 0;
	}
	LOG_INF("BLE Transport initialized successfully");

	/* Register USB callbacks with BLE Transport */
	ble_transport_register_usb_cdc_callback((usb_cdc_send_cb_t)mouthpad_nus_data_received_callback);
	ble_transport_register_usb_hid_callback(usb_hid_data_callback);

	/* Start bridging */
	ble_transport_start_bridging();

	LOG_INF("Starting USB ↔ BLE bridge (NUS + HID)");

	/* Initialize LED subsystem */
	LOG_INF("Initializing LED subsystem...");
	err = leds_init();
	if (err != 0) {
		LOG_WRN("leds_init failed (err %d) - continuing without LEDs", err);
		/* Continue without LEDs - not critical for core functionality */
	} else {
		LOG_INF("LED subsystem initialized successfully");
		
		/* Choose color mode based on LED hardware */
		if (leds_has_neopixel()) {
			/* NeoPixel supports smooth gradients */
			leds_set_battery_color_mode(BAS_COLOR_MODE_GRADIENT);
			LOG_INF("Using gradient mode for NeoPixel LEDs");
		} else {
			/* GPIO LEDs work better with discrete colors */
			leds_set_battery_color_mode(BAS_COLOR_MODE_DISCRETE);
			LOG_INF("Using discrete mode for GPIO LEDs");
		}
		
		leds_set_state(LED_STATE_SCANNING);  /* Start in scanning state */
	}
	
	/* Initialize User Button */
	LOG_INF("Initializing user button...");
	err = button_init();
	if (err != 0) {
		LOG_WRN("button_init failed (err %d) - continuing without button", err);
		/* Continue without button - not critical for core functionality */
	} else {
		LOG_INF("User button initialized successfully");
		button_register_callback(button_event_callback);
	}
	
	static int display_update_counter = 0;

	/* Reset display state after splash screen to ensure status updates work */
	if (oled_display_is_available()) {
		oled_display_reset_state();
	}

	/* Packet framing state machine for CDC RX */
	enum {
		FRAME_STATE_SEARCH_MAGIC1,  // Looking for 0xAA
		FRAME_STATE_SEARCH_MAGIC2,  // Looking for 0x55
		FRAME_STATE_LENGTH_HIGH,    // Reading length high byte
		FRAME_STATE_LENGTH_LOW,     // Reading length low byte
		FRAME_STATE_PAYLOAD,        // Reading payload
		FRAME_STATE_CRC_HIGH,       // Reading CRC high byte
		FRAME_STATE_CRC_LOW         // Reading CRC low byte
	} frame_state = FRAME_STATE_SEARCH_MAGIC1;

	static uint8_t frame_buffer[512];
	static uint16_t frame_length = 0;
	static uint16_t frame_pos = 0;
	static uint16_t expected_crc = 0;

	LOG_INF("Entering main loop...");

	for (;;) {
		/* USB CDC ↔ BLE NUS Bridge */

		/* Check BLE connection status and HID data activity */
		bool is_connected = ble_transport_is_connected();
		bool ble_hid_activity = ble_transport_has_hid_data_activity();
		uint8_t battery_level = ble_bas_get_battery_level();
		int8_t rssi_dbm = is_connected ? ble_transport_get_rssi() : 0;

		// Check for data from USB CDC - parse framed packets [0xAA 0x55][len][payload][CRC]
		uint8_t c;
		int bytes_read = usb_cdc_receive_data(&c, 1);

		if (bytes_read > 0) {
			switch (frame_state) {
				case FRAME_STATE_SEARCH_MAGIC1:
					if (c == 0xAA) {
						frame_state = FRAME_STATE_SEARCH_MAGIC2;
					}
					break;

				case FRAME_STATE_SEARCH_MAGIC2:
					if (c == 0x55) {
						frame_state = FRAME_STATE_LENGTH_HIGH;
						frame_pos = 0;
					} else if (c != 0xAA) {
						// Not magic byte sequence, restart search
						frame_state = FRAME_STATE_SEARCH_MAGIC1;
					}
					// If c == 0xAA, stay in SEARCH_MAGIC2 (could be start of new frame)
					break;

				case FRAME_STATE_LENGTH_HIGH:
					frame_length = (uint16_t)c << 8;
					frame_state = FRAME_STATE_LENGTH_LOW;
					break;

				case FRAME_STATE_LENGTH_LOW:
					frame_length |= c;
					if (frame_length > sizeof(frame_buffer)) {
						LOG_ERR("Frame too large: %d bytes", frame_length);
						frame_state = FRAME_STATE_SEARCH_MAGIC1;
					} else {
						frame_state = FRAME_STATE_PAYLOAD;
						frame_pos = 0;
					}
					break;

				case FRAME_STATE_PAYLOAD:
					frame_buffer[frame_pos++] = c;
					if (frame_pos >= frame_length) {
						frame_state = FRAME_STATE_CRC_HIGH;
					}
					break;

				case FRAME_STATE_CRC_HIGH:
					expected_crc = (uint16_t)c << 8;
					frame_state = FRAME_STATE_CRC_LOW;
					break;

				case FRAME_STATE_CRC_LOW:
					expected_crc |= c;

					// Validate CRC
					uint16_t calculated_crc = calculate_crc16(frame_buffer, frame_length);
					if (calculated_crc != expected_crc) {
						LOG_ERR("CRC mismatch: calc=0x%04X, expected=0x%04X", calculated_crc, expected_crc);
						frame_state = FRAME_STATE_SEARCH_MAGIC1;
						break;
					}

					// Valid framed packet received!
					LOG_DBG("Framed packet RX: %d bytes", frame_length);

					// Decode protobuf message
					mouthware_message_AppToRelayMessage message;
					pb_istream_t stream = pb_istream_from_buffer(frame_buffer, frame_length);
					if (!pb_decode(&stream, mouthware_message_AppToRelayMessage_fields, &message)) {
						LOG_ERR("Protobuf decode failed: %s", PB_GET_ERROR(&stream));
						frame_state = FRAME_STATE_SEARCH_MAGIC1;
						break;
					}

					// Handle message
					switch (message.destination) {
						case mouthware_message_AppToRelayMessageDestination_APP_RELAY_MESSAGE_DESTINATION_RELAY:
							if (message.which_message_body == mouthware_message_AppToRelayMessage_ble_connection_status_read_tag) {
								mouthware_message_RelayToAppMessage response = mouthware_message_RelayToAppMessage_init_zero;
								response.which_message_body = mouthware_message_RelayToAppMessage_ble_connection_status_response_tag;

								/* Use ble_central state machine as the ONLY source of truth for connection status */
								LOG_INF("=== BLE STATUS QUERY ===");
								bool central_connecting = ble_central_is_connecting();
								bool central_scanning = ble_central_is_scanning();
								bool central_connected = ble_central_is_connected();
								LOG_INF("Query state: connecting=%d, scanning=%d, connected=%d (transport is_connected=%d)",
								        central_connecting, central_scanning, central_connected, is_connected);

								if (central_connecting) {
									LOG_INF("Reporting: CONNECTING");
									response.message_body.ble_connection_status_response.connection_status = mouthware_message_RelayBleConnectionStatus_RELAY_CONNECTION_STATUS_CONNECTING;
								} else if (central_scanning) {
									LOG_INF("Reporting: SEARCHING");
									response.message_body.ble_connection_status_response.connection_status = mouthware_message_RelayBleConnectionStatus_RELAY_CONNECTION_STATUS_SEARCHING;
								} else if (central_connected) {
									LOG_INF("Reporting: CONNECTED (via ble_central state)");
									response.message_body.ble_connection_status_response.connection_status = mouthware_message_RelayBleConnectionStatus_RELAY_CONNECTION_STATUS_CONNECTED;
								} else {
									/* Default to DISCONNECTED if all other checks fail */
									LOG_INF("Reporting: DISCONNECTED");
									response.message_body.ble_connection_status_response.connection_status = mouthware_message_RelayBleConnectionStatus_RELAY_CONNECTION_STATUS_DISCONNECTED;
								}

								response.message_body.ble_connection_status_response.rssi = rssi_dbm;
								response.message_body.ble_connection_status_response.battery_level = battery_level;
								usb_cdc_send_proto_message_async(response);
							} else if (message.which_message_body == mouthware_message_AppToRelayMessage_device_info_read_tag) {
								/* Handle DeviceInfoRead request */
								mouthware_message_RelayToAppMessage response = mouthware_message_RelayToAppMessage_init_zero;
								response.which_message_body = mouthware_message_RelayToAppMessage_device_info_response_tag;

								/* Check if we have a bonded device (even if disconnected) */
								bt_addr_le_t bonded_addr;
								static char bonded_name[32];
								bool has_bonded = ble_central_get_bonded_device_addr(&bonded_addr, bonded_name, sizeof(bonded_name));

								/* Get BLE address - prefer active connection, fallback to bonded address */
								static char ble_addr_str[BT_ADDR_STR_LEN];
								struct bt_conn *conn = ble_central_get_default_conn();

								if (conn) {
									/* Device is currently connected - get address from connection */
									const bt_addr_le_t *addr_le = bt_conn_get_dst(conn);
									bt_addr_to_str(&addr_le->a, ble_addr_str, sizeof(ble_addr_str));
									response.message_body.device_info_response.address.funcs.encode = encode_string_callback;
									response.message_body.device_info_response.address.arg = (void *)ble_addr_str;
								} else if (has_bonded) {
									/* Device is bonded but not connected - return cached address */
									bt_addr_to_str(&bonded_addr.a, ble_addr_str, sizeof(ble_addr_str));
									response.message_body.device_info_response.address.funcs.encode = encode_string_callback;
									response.message_body.device_info_response.address.arg = (void *)ble_addr_str;
								}

								/* Get device name - prefer live name from active connection, fallback to cached name */
								const char *device_name = NULL;
								if (conn) {
									/* Get advertised device name from BLE transport (live connection) */
									device_name = ble_transport_get_device_name();
								}

								/* If no live name available but we have a cached bonded name, use that */
								if ((!device_name || device_name[0] == '\0') && has_bonded && bonded_name[0] != '\0') {
									device_name = bonded_name;
								}

								/* Encode device name if we have one */
								if (device_name && device_name[0] != '\0') {
									response.message_body.device_info_response.name.funcs.encode = encode_string_callback;
									response.message_body.device_info_response.name.arg = (void *)device_name;
								}

								/* Get device info from DIS client for the specific device
								 * Prefer connected device, fallback to first bonded device */
								static ble_dis_info_t dis_info_buf;
								const bt_addr_le_t *target_addr = NULL;

								if (conn) {
									/* Get DIS info for currently connected device */
									target_addr = bt_conn_get_dst(conn);
								} else if (has_bonded) {
									/* Get DIS info for first bonded device */
									target_addr = &bonded_addr;
								}

								int dis_err = -ENOENT;
								if (target_addr) {
									dis_err = ble_dis_load_info_for_addr(target_addr, &dis_info_buf);
								}

								if (dis_err == 0) {
									LOG_INF("DIS info loaded: has_fw=%d, has_pnp=%d",
										dis_info_buf.has_firmware_version, dis_info_buf.has_pnp_id);
									/* Firmware version */
									if (dis_info_buf.has_firmware_version) {
										LOG_INF("DIS firmware: %s", dis_info_buf.firmware_version);
										response.message_body.device_info_response.firmware.funcs.encode = encode_string_callback;
										response.message_body.device_info_response.firmware.arg = (void *)dis_info_buf.firmware_version;
									}
									/* VID and PID from PnP ID */
									if (dis_info_buf.has_pnp_id) {
										LOG_INF("DIS PnP ID: VID=0x%04X, PID=0x%04X",
											dis_info_buf.vendor_id, dis_info_buf.product_id);
										response.message_body.device_info_response.vid = dis_info_buf.vendor_id;
										response.message_body.device_info_response.pid = dis_info_buf.product_id;
									}
								} else {
									LOG_WRN("DIS info not available for device (err: %d)", dis_err);
								}

								/* Device family and board (always available) */
								response.message_body.device_info_response.family = mouthware_message_DeviceFamily_DEVICE_FAMILY_NRF;

								/* Map board name string to enum value */
								const char *board_name;
								#ifdef CONFIG_DONGLE_VARIANT_STRING
									const char *variant_str = CONFIG_DONGLE_VARIANT_STRING;
									if (variant_str && variant_str[0] != '\0') {
										board_name = variant_str;
									} else {
										board_name = CONFIG_BOARD;
									}
								#else
									board_name = CONFIG_BOARD;
								#endif
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

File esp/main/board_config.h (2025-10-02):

#pragma once

#include "sdkconfig.h"
#include "driver/gpio.h"

// Board configuration from Kconfig
#define BOARD_NAME              CONFIG_MOUTHPAD_BOARD_NAME
#define BOARD_BUTTON_GPIO       (gpio_num_t)CONFIG_MOUTHPAD_BUTTON_GPIO

// LED defaults per board, with optional override from Kconfig
#if CONFIG_MOUTHPAD_LED_GPIO >= 0
    #define BOARD_LED_GPIO          (gpio_num_t)CONFIG_MOUTHPAD_LED_GPIO
    #define BOARD_LED_ACTIVE_LOW    CONFIG_MOUTHPAD_LED_ACTIVE_LOW
#elif CONFIG_MOUTHPAD_BOARD_XIAO_ESP32S3
    #define BOARD_LED_GPIO          GPIO_NUM_21
    #define BOARD_LED_ACTIVE_LOW    1
#elif CONFIG_MOUTHPAD_BOARD_LILYGO_T_DISPLAY_S3
    /* No user LED available */
#endif

// Board-specific pin definitions for T-Display-S3
#ifdef CONFIG_MOUTHPAD_BOARD_LILYGO_T_DISPLAY_S3
    // Display pins (reserved for future display implementation)
    #define BOARD_LCD_MOSI          GPIO_NUM_13
    #define BOARD_LCD_SCLK          GPIO_NUM_12
    #define BOARD_LCD_CS            GPIO_NUM_10
    #define BOARD_LCD_DC            GPIO_NUM_11
    #define BOARD_LCD_RST           GPIO_NUM_9
    #define BOARD_LCD_BL            GPIO_NUM_15  // Display backlight control
    #define BOARD_PWR_EN            GPIO_NUM_15  // Power enable
#endif

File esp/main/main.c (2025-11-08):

#include <stdio.h>
#include <string.h>

#include "freertos/FreeRTOS.h"
#include "freertos/task.h"

#include "esp_bt.h"
#include "esp_bt_defs.h"
#include "esp_bt_main.h"
#include "esp_event.h"
#include "esp_gap_ble_api.h"
#include "esp_log.h"
#include "esp_timer.h"
#include "nvs_flash.h"

#include "esp_hid_common.h"
#include "esp_hidh.h"
#include "esp_hidh_gattc.h"
#include "ble_central.h"
#include "usb_hid.h"
#include "driver/uart.h"
#include "usb_dfu.h"
#include "ble_bas.h"
#include "leds.h"
#include "transport_uart.h"
#include "ble_nus.h"
#include "app_config.h"
#include "button.h"
#include "ble_dis.h"
#include "transport_hid.h"
#include "ble_hid.h"
#include "ble_bonds.h"
#include "relay_protocol.h"

static const char *TAG = "MP_MAIN";

// s_active_dev now managed by transport_hid and ble_hid modules
static esp_bd_addr_t s_active_addr;
static esp_timer_handle_t s_rssi_timer;
static bool s_rssi_timer_running;
static esp_timer_handle_t s_service_discovery_timer;
static bool s_has_active_addr;
static uint16_t s_active_conn_id = 0xFFFF;
static esp_gatt_if_t s_active_gattc_if = ESP_GATT_IF_NONE;
static esp_gatt_if_t s_nus_gattc_if = ESP_GATT_IF_NONE;  // Separate interface for NUS
static esp_gatt_if_t s_dis_gattc_if = ESP_GATT_IF_NONE;  // Separate interface for DIS
static esp_gatt_if_t s_hid_gattc_if = ESP_GATT_IF_NONE;  // HID GATT interface (app_id 0)

// Advertisement data from the connected device
static uint16_t s_active_appearance = 0;
static uint8_t s_active_manufacturer_data[32] = {0};
static uint8_t s_active_manufacturer_len = 0;

// appearance_to_string moved to ble_hid.c

static void schedule_rssi_poll(void)
{
    if (!ble_hid_client_is_connected() || !s_has_active_addr) {
        return;
    }
    esp_err_t err = esp_ble_gap_read_rssi(s_active_addr);
    if (err != ESP_OK) {
        ESP_LOGW(TAG, "Failed to request RSSI: %s", esp_err_to_name(err));
    }
}

static void rssi_timer_callback(void *arg)
{
    (void)arg;
    schedule_rssi_poll();
}

static void start_rssi_timer(void)
{
    if (s_rssi_timer_running) {
        return;
    }
    if (!s_rssi_timer) {
        const esp_timer_create_args_t args = {
            .callback = rssi_timer_callback,
            .name = "rssi_poll",
        };
        ESP_ERROR_CHECK(esp_timer_create(&args, &s_rssi_timer));
    }
    ESP_ERROR_CHECK(esp_timer_start_periodic(s_rssi_timer, 10 * 1000 * 1000));
    s_rssi_timer_running = true;
}

static void stop_rssi_timer(void)
{
    if (!s_rssi_timer_running || !s_rssi_timer) {
        return;
    }
    ESP_ERROR_CHECK(esp_timer_stop(s_rssi_timer));
    s_rssi_timer_running = false;
}

// Helper functions log_report and log_addr moved to ble_hid.c

static void service_discovery_timer_callback(void *arg)
{
    ESP_LOGI(TAG, "Starting delayed NUS and DIS service discovery");

    // Start NUS service discovery
#if ENABLE_NUS_CLIENT_MODE
    if (s_has_active_addr) {
        ble_nus_client_set_server_bda(s_active_addr);
        if (s_active_conn_id != 0xFFFF && s_nus_gattc_if != ESP_GATT_IF_NONE) {
            esp_err_t ret = transport_uart_discover_services(s_nus_gattc_if, s_active_conn_id);
            if (ret != ESP_OK) {
                ESP_LOGW(TAG, "Failed to start NUS service discovery: %s", esp_err_to_name(ret));
            }
        }
    }
#endif

    // Start DIS service discovery (runs in parallel with NUS)
    if (s_active_conn_id != 0xFFFF && s_dis_gattc_if != ESP_GATT_IF_NONE && s_has_active_addr) {
        esp_err_t ret = ble_device_info_discover(s_dis_gattc_if, s_active_conn_id, s_active_addr, "RDSMouthPad");
        if (ret != ESP_OK) {
            ESP_LOGW(TAG, "Failed to start DIS service discovery: %s", esp_err_to_name(ret));
        }
    }
}

static bool addr_matches_active(const uint8_t *addr)
{
    return s_has_active_addr && addr && memcmp(addr, s_active_addr, sizeof(s_active_addr)) == 0;
}

static void gap_callback(esp_gap_ble_cb_event_t event, esp_ble_gap_cb_param_t *param)
{
    switch (event) {
    case ESP_GAP_BLE_READ_RSSI_COMPLETE_EVT:
        if (param->read_rssi_cmpl.status == ESP_BT_STATUS_SUCCESS &&
            addr_matches_active(param->read_rssi_cmpl.remote_addr)) {
            ESP_LOGI(TAG, "RSSI update: addr=%02X:%02X:%02X:%02X:%02X:%02X, rssi=%d dBm",
                     param->read_rssi_cmpl.remote_addr[0], param->read_rssi_cmpl.remote_addr[1],
                     param->read_rssi_cmpl.remote_addr[2], param->read_rssi_cmpl.remote_addr[3],
                     param->read_rssi_cmpl.remote_addr[4], param->read_rssi_cmpl.remote_addr[5],
                     param->read_rssi_cmpl.rssi);

            // Update relay protocol with RSSI value
            relay_protocol_update_rssi(param->read_rssi_cmpl.rssi);
        } else {
            ESP_LOGW(TAG, "RSSI read failed: 0x%x", param->read_rssi_cmpl.status);
        }
        break;
    case ESP_GAP_BLE_UPDATE_CONN_PARAMS_EVT:
        if (param->update_conn_params.status == ESP_BT_STATUS_SUCCESS) {
            ESP_LOGI(TAG, "Connection params updated: interval=%d, latency=%d, timeout=%d",
                     param->update_conn_params.conn_int,
                     param->update_conn_params.latency,
                     param->update_conn_params.timeout);

            // Notify NUS client that connection is now stable
            ble_nus_client_connection_ready();
        } else {
            ESP_LOGW(TAG, "Connection params update failed: 0x%x", param->update_conn_params.status);
        }
        break;
    default:
        break;
    }
}

static void start_scan_task(void);

// Track whether we've reported Connected state yet
static bool s_connection_state_reported = false;

// Public function to check if we're ready to report Connected state
bool ble_connection_is_fully_ready(void)
{
    return s_connection_state_reported;
}

// Called when NUS service is fully ready (CCCD enabled and notifications working)
void nus_ready_callback(void)
{
    ESP_LOGI(TAG, "NUS service is ready");

    // Check if we have cached device info with firmware version
    if (ble_device_info_has_cached_firmware()) {
        ESP_LOGI(TAG, "Cached device info exists - reporting Connected state immediately");
        s_connection_state_reported = true;
        // Note: Connected state is determined by relay_protocol checking:
        // s_ble_connected && ble_hid_client_is_connected()
        // These are already set by hid_connected_cb, so app will see Connected state now
    } else {
        ESP_LOGI(TAG, "No cached device info - waiting for DIS to complete before reporting Connected");
        // s_connection_state_reported stays false, will be set in device_info_complete_callback
    }
}
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

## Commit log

2025-07-18 Major repository cleanup and organization
    🎯 Repository Cleanup:
    - Reduced repository size from 3.8GB to ~352KB (99.99% reduction)
    - Removed 80,000+ unnecessary files (dependencies managed by West)
    - Added comprehensive .gitignore for Zephyr/NCS projects
    📁 Script Organization:
    - Moved all scripts to dedicated scripts/ directory
    - Updated Makefile to reference new script locations
    - Added cleanup target to Makefile
    🔧 Build System Improvements:
    - Added proper Zephyr project structure (CMakeLists.txt, prj.conf)
    - Added West manifest (west.yml) for dependency management
    - Enhanced DFU command with Nordic-specific bootloader triggers
    - Improved flash scripts with better error handling a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
    [main.c]
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2025-07-24 feat: restarts with fresh base implementation of ble central hids and builds, flashes, pairs and prints hid reports of a mouthpad without issue
    [main.c]
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2025-08-03 feat: Major UI/UX improvements and data parsing fixes
    ## Web Interface Enhancements
    ### UI Layout Redesign
    - Implemented responsive two-column layout with left column for visuals (connection/grid/chart) and right column for controls (terminal/commands)
    - Added CSS Grid layout with auto-sizing right column to match grid width
    - Improved responsive breakpoint at 900px with proper column stacking order
    - Reduced padding and spacing for more compact, efficient layout
    ### Grid Visualization Improvements
    - Fixed grid orientation to match Mac app by reversing capacitance array before grid update
    - Implemented golden gradient visualization (rgba(0,0,0,0) to #dca32f) for better visual feedback
    - Ad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
    [main.c]
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2025-08-04 refactor: modularize /app BLE firmware for future merge preparation
    - Split monolithic ble.c/h into modular components:
    * ble_transport.c/h: Unified transport layer orchestrating BLE Central and HID
    * ble_central.c/h: BLE Central functionality (scanning, connection, GATT discovery)
    * ble_hid.c/h: BLE HID client functionality (HOGP, button handling)
    - Removed old ble.c/h files
    - Updated CMakeLists.txt to include new modular source files
    - Fixed main.c return type and error handling
    - Added callback registration system for inter-module communication
    - Prepared dual-protocol architecture for future NUS/HID bridge merge
    - All builds successfully with clean modular structure
    [main.c]
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2025-08-05 feat: Merge UART and HID BLE bridges into unified end-to-end system
    BREAKING: Complete firmware architecture overhaul - dual-mode USB ↔ BLE bridge
    Core Achievement:
    - ✅ MERGED two separate BLE transport bridges (UART/NUS + HID) into single system
    - ✅ END-TO-END working: USB CDC ↔ BLE NUS + USB HID ↔ BLE HID
    - ✅ FIXED BLE HID discovery error -120 (ENODEV) with callback-based sequential discovery
    - ✅ RESOLVED GATT discovery conflicts between NUS and HID services
    Firmware Architecture:
    - Modular BLE Central with dual-service detection (NUS + HID)
    - Sequential discovery: NUS completes → triggers HID discovery
    - Proper HOGP initialization and discovery callbacks
    - Dual-mode USB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
    [main.c]
2025-08-14 fix: corrects initial pairing security failure due to change in recent Zephyr sdk update that defaults to not supporting legacy pairing methods; kept a lot of changes in hid sample that came about de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
    [main.c]
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2025-08-15 feat: add Battery Service client with USB HID semaphore fix
    - Add Battery Service (BAS) client support following Nordic central_bas pattern
    - Implement battery level monitoring with periodic reads every 10 seconds
    - Add battery notifications and discovery callbacks
    - Fix USB HID endpoint semaphore contention causing -11 errors and latency
    - Replace blocking K_FOREVER semaphore calls with 50ms timeouts in BLE HID path
    - Remove duplicate USB HID sending in transport layer to avoid conflicts
    - Reduce logging verbosity for HID data processing to debug level
    - Add CONFIG_BT_BAS_CLIENT=y configuration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
    [main.c]
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2025-08-16 feat: add OLED display support for XIAO Expansion Board
    - Add SSD1306 OLED display driver integration with device tree overlay
    - Implement responsive battery level and connection status display
    - Add visual battery icon with 5-level charge indication ([||||] to [.....])
    - Enable automatic display detection (graceful fallback when not present)
    - Configure inverted display (white text on black background)
    - Optimize update frequency to 100ms for responsive connection changes
    - Restore USB CDC UART bridge functionality with proper device handling
    - Fix system stability issues and USB initialization conflicts
    - Add comprehensive error handling for optional hardware components
    🤖 Generated wit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
    [main.c]
2025-08-16 feat: add animated splash screen with Augmental logo
    Implement professional boot sequence with inverted logo bitmap and fade effects:
    - Add PNG to C bitmap converter for Augmental logo
    - Implement fade in/out transitions using SSD1306 contrast control
    - Create seamless splash-to-status transition without flicker
    - Add display state reset for reliable status updates
    - Support automatic fallback when display not present
    [main.c]
2025-08-16 feat: add PWM buzzer support with audio feedback and fix connection issues
    ## Buzzer Features
    - Add PWM-based passive buzzer driver with multiple click sound variations
    - Implement different sounds for left/right mouse clicks for better tactile feedback
    - Add happy connection sound (rising C-E-G melody) when device fully connects
    - Add sad disconnection sound (falling G-E-C melody) for device disconnections
    - Support mechanical, pop, and double-click sound variations
    - Graceful fallback when buzzer hardware not available
    ## Connection State Fixes
    - Fix premature disconnect sound playing during connection phases
    - Add connection state tracking to only play disconnect sound after full connect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
    [main.c]
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2025-08-19 feat: add brightness control for NeoPixel LEDs
    - Add configurable brightness scaling (default 25/255 for comfortable viewing)
    - Scale all RGB values to prevent blinding brightness
    - Apply brightness control to startup indication pulse
    - Maintain color accuracy while reducing intensity
    [leds.c]
2025-08-19 feat: implement comprehensive user button support with hardware workarounds
    - Add button.c/h module with click, double-click, and hold event detection
    - Support XIAO expansion board (D1) and Feather nRF52840 user buttons
    - Implement robust debouncing and state machine for reliable event detection
    - Add hardware workaround for stuck-low GPIO pins (common XIAO issue)
    - Hold event (2s) disconnects BLE and clears all bonds for device reset
    - Click and double-click events logged (ready for future functionality)
    - Add BLE disconnect and bond clearing functions to ble_transport
    - Support both boards with automatic hardware detection
    Button Features:
    - 50ms debounce time with state machine processi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
    [button.c, main.c]
2025-08-19 feat: implement real-time BLE connection RSSI monitoring
    - Add continuous RSSI reading using HCI Read RSSI command
    - Replace simulated RSSI values with actual hardware measurements
    - Implement periodic RSSI updates every 2 seconds during active connections
    - Add comprehensive BLE signal strength optimizations (TX power, PHY modes, data length extension)
    - Based on Zephyr HCI Power Control sample implementation
    - Provides real-time signal strength changes for meaningful BLE testing
    - Clean up unused variables and fix deprecation warnings
    [button.c, main.c]
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2025-09-25 feat(esp32): implement separate GATT instances for HID and NUS services
    - Registers dedicated GATT client application (app_id=1) for NUS service
    - Maintains ESP HID library's existing GATT client (app_id=0) for HID service
    - Implements proper GATT connection establishment using esp_ble_gattc_open()
    - Routes GATT events based on interface to prevent service conflicts
    - Adds delayed NUS discovery after HID connection to avoid timing conflicts
    - Fixes HID reconnection issues by isolating NUS and HID service operations
    - Both HID mouse reports and NUS data transmission now work simultaneously
    - Maintains functionality across disconnect/reconnect cycles
    This follows ESP-IDF best practices for mu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
    [main.c]
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2025-09-25 feat(esp32): implement user button module with GPIO0 interrupt handling
    - Add button.c/h module for XIAO ESP32-S3 boot button (GPIO0)
    - Support single-click, double-click, and long-press detection
    - Implement non-blocking time-based debouncing to prevent watchdog issues
    - Long-press triggers BLE bond clearing functionality
    - Use FreeRTOS tasks and ESP timers for reliable event handling
    - Fixed GPIO0 strapping pin compatibility issues
    [button.c, main.c]
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2025-09-26 refactor(esp32): rename ble_nus_client to ble_nus for cleaner naming
    - Rename ble_nus_client.c/.h to ble_nus.c/.h
    - Update all includes from "ble_nus_client.h" to "ble_nus.h"
    - Update CMakeLists.txt to reference new filenames
    - No functional changes, purely naming cleanup
    Since the unused NUS GATT server code was removed, the "client" suffix
    is no longer needed - the remaining NUS code is clearly for client functionality.
    This provides cleaner, more intuitive naming:
    Before: ble_nus_client.c (NUS client) + ble_nus.c (unused server)
    After: ble_nus.c (NUS client only)
    [main.c]
2025-09-26 refactor(esp32): rename ble_device_info to ble_dis for cleaner naming
    - Rename ble_device_info.c/.h to ble_dis.c/.h
    - Update all includes from "ble_device_info.h" to "ble_dis.h"
    Rationale: "ble_dis" is more concise and aligns with standard BLE terminology:
    - DIS = Device Information Service (standard BLE service)
    - Matches naming pattern with other BLE services (ble_nus, ble_bas)
    - Shorter, cleaner naming convention
    ESP32 BLE architecture now uses consistent naming:
    ├── ble_nus.c/h - Nordic UART Service client
    ├── ble_dis.c/h - Device Information Service client
    └── ble_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
    [main.c]
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2025-09-26 feat(esp32): implement NUS UUID filtering and fix stuck HID inputs
    - Add Nordic UART Service (NUS) UUID detection in BLE advertisements
    - Filter devices by both HID service (0x1812) and NUS UUID for unique identification
    - Implement usb_hid_release_all() to send neutral reports and prevent stuck inputs
    - Add transport_hid_handle_disconnect() to release inputs on device disconnect
    - Enhanced advertisement packet logging shows NUS UUID detection status
    - Replace unreliable device name filtering with robust UUID-based matching
    This prevents connection cycling to random BLE devices and ensures stuck
    mouse buttons/movement are properly released when devices disconnect.
    🤖 Generated with [Clau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
    [main.c]
2025-09-26 feat(esp32): implement comprehensive BLE bonding system with enhanced scanning
    - Add ble_bonds module for persistent single-device bonding with NVS storage
    - Implement proper BLE GAP disconnect to notify MouthPad of disconnection
    - Add intelligent device selection prioritizing bonded devices over new ones
    - Replace repetitive scanning logs with clear per-cycle status messages
    - Fix compiler warnings in ble_central.c const qualifier handling
    - Update TAG to "MP_MAIN" for clearer log identification
    - Add bond clearing via long button press with proper device disconnection
    [main.c]
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2025-09-29 fix(april-brothers): correct RGB LED and button implementation
    Fixed LED color mapping and GPIO logic for April Brothers nRF52840 dongle:
    LED Changes:
    - Discovered physical LED pins are wired differently than wiki documentation
    - Wiki: Red=P0.08, Green=P1.09, Blue=P0.12
    - Actual: Blue=P0.08, Red=P1.09, Green=P0.12
    - Remapped devicetree aliases to compensate for physical wiring
    - Fixed double-inversion bug: removed manual GPIO inversion since
    GPIO_ACTIVE_LOW in devicetree handles it automatically
    - This fix applies to all boards (XIAO, Feather, April Brothers)
    - Disabled standalone LED1 (P0.06) to use only RGB LED2
    Button Changes:
    - Configured button on P1.06 (SW1) - verified working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
    [leds.c]
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2025-10-01 refactor(logging): convert all printk to LOG_* macros and disable ANSI colors
    - Convert all printk() calls to appropriate LOG_*() macros across codebase
    - Disable colored output (CONFIG_LOG_BACKEND_SHOW_COLOR=n) to remove ANSI escape codes
    - Disable timestamps (CONFIG_LOG_BACKEND_FORMAT_TIMESTAMP=n) for cleaner output
    - Fix duplicate scanning messages by simplifying scan indicator logic
    - Stop scanning when connected by setting scanning_active=false
    - All log messages now properly tagged with module names (ble_hid, ble_central, etc.)
    Files changed:
    - app/prj.conf: Disable log colors and timestamps
    - app/src/ble_hid.c: Convert all printk to LOG_INF/ERR/DBG/WRN
    - app/src/ble_central.c: Conver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
    [main.c]
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2025-10-02 fix: align nRF USB identity with ESP32 build
    - format the USB serial number from the first six HWID bytes so macOS
    assigns the same usbmodem paths as the ESP32 firmware
    - assign fixed CDC interface strings (MouthPad^NUS / MouthPad^CDC) and
    force bcdDevice to 0x0001 so hosts report the same version
    - update the Zephyr USB config: mark the device as bus‑powered,
    advertise 100 mA (MaxPower=50), cap HWINFO device ID length at 8 bytes,
    and enable USB debug logging for descriptor troubleshooting
    [main.c]
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2025-10-06 fix(hid): resolve stuck mouse buttons on BLE disconnect
    Corrects HID Report ID 1 format from 3 to 4 bytes to match actual device
    structure, preventing buttons from remaining stuck when BLE device
    disconnects while pressed. The 4th byte represents AC Pan which was missing.
    Also prioritizes sending clear reports before disconnect sound and adds
    connection guards to prevent stale data forwarding during disconnect.
    [main.c]
2025-10-06 chore: eliminate all build warnings and improve configuration
    Source code fixes:
    - Wrap unused legacy UART functions in usb_cdc.c with #if 0
    - Add BUTTON_STATE_RELEASED case to button state machine
    - Guard NeoPixel functions with HAS_NEOPIXEL and fix missing return
    - Mark conditionally unused functions with __maybe_unused
    - Remove unused forward declarations in ble_central.c and oled_display.c
    - Fix format string in ble_hid.c debug log (%s -> %d)
    - Fix pointer type in main.c NUS data forwarding
    Configuration improvements:
    - Reduce USB device stack logging from DBG to WRN (quieter console)
    - Explicitly disable CDC ACM logging to suppress recursion warning
    - Rename mcuboot_pad -> adafruit_boo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
    [button.c, leds.c, main.c]
2025-10-06 refactor: restructure repository with isolated NCS and ESP workspaces
    Separate Nordic Connect SDK and ESP32 into isolated workspace directories
    to prevent build conflicts and improve project organization.
    **Changes:**
    - Move nRF/NCS files to `ncs/` directory (app/, bootloaders/, Makefile, west.yml, docker-compose.yml)
    - Rename `esp32/` → `esp/` for consistency
    - Create `ncs/.gitignore` for NCS workspace-specific files
    - Clean up root `.gitignore` by removing NCS-specific entries (43 lines)
    - Update README.md with new directory structure and paths
    - Move logo assets to `assets/` directory
    - Remove obsolete root-level build scripts in `scripts/`
    - Remove AGENTS.md and CLAUDE.md (now in sepa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
    [mouthpad_usb.f3d, mouthpad_usb.step, mouthpad_usb_bottom.stl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]
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2025-10-07 refactor: rename `clear` command to `reset` on both platforms
    Changes CDC console command from `clear` to `reset` for consistency
    and clarity. The command disconnects from MouthPad^, clears BLE bonds,
    and returns to scanning/pairing mode.
    - ESP32: Update usb_cdc.c command parsing from "clear" to "reset"
    - nRF52: Rename cmd_clear() to cmd_reset() and SHELL_CMD_REGISTER
    - Update all documentation (main README, esp/README, ncs/app/README)
    Command behavior unchanged - only the command name is different.
    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
    [main.c]
2025-10-07 feat: add `restart` command to CDC console on both platforms
    Adds software reset capability via CDC maintenance console for both
    ESP32 and nRF52 firmwares. Useful for quickly restarting firmware
    without physical access to reset button.
    - ESP32: Add `restart` command using `esp_restart()` in usb_cdc.c
    - nRF52: Add `restart` command using `sys_reboot(SYS_REBOOT_COLD)` in main.c
    Usage: Send `restart` to CDC port 1 (maintenance console) to trigger
    a clean software reset. Gives 100ms for logs to flush before reboot.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
    [main.c]
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2025-10-07 feat: add `version` command to both ESP32 and nRF52 firmwares
    Adds a new CDC console command `version` that displays firmware build
    information on demand, addressing the issue that early boot logs
    containing version info are not visible on ESP32 without physical UART.
    ESP32 version output:
    - Firmware name (MouthPad^USB (ESP32))
    - Build timestamp (__DATE__ and __TIME__)
    - ESP-IDF version
    - Chip model, revision, and CPU cores
    nRF52 version output:
    - Firmware name (MouthPad^USB (nRF52))
    - Build timestamp (__DATE__ and __TIME__)
    - Zephyr kernel version (KERNEL_VERSION_STRING)
    - App version (if BUILD_VERSION defined)
    This provides an easy way to check firmware version and build info
    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
    [main.c]
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2025-10-07 fix(nrf): lock NCS to v3.1.0 and fix restart command
    - Lock docker-compose.yml to NCS v3.1.0 (was using main branch)
    - Change restart command from sys_reboot() to NVIC_SystemReset()
    for compatibility with NCS v3.1.0 and consistency with DFU command
    - Remove unused zephyr/sys/reboot.h include
    - Simplified version command (removed KERNEL_VERSION_STRING which
    doesn't exist in NCS v3.1.0)
    Note: nrf52840dongle_nrf52840.overlay modified by build-april-dongle
    target, reverted to Nordic PCA10059 defaults.
    [main.c]
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2025-10-08 fix(esp): write CCCD descriptor to enable NUS notifications
    Critical bug fix: esp_ble_gattc_register_for_notify() only registers
    the client-side handler but does NOT write the CCCD descriptor to tell
    the device to send notifications.
    Without this, the MouthPad device correctly reports "no listeners to NUS"
    because the CCCD was never written.
    - Add esp_ble_gattc_write_char_descr() to write 0x0001 to CCCD after
    discovering NUS TX characteristic
    - CCCD handle is characteristic_handle + 1 per BLE spec
    - Update ESP_GATTC_WRITE_DESCR_EVT handler to check correct handle
    - Add detailed logging for debugging
    Co-Authored-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
    [main.c]
2025-10-13 Implement packet framing for CDC communication and update protobuf schema
    This commit contains two related changes:
    1. Packet Framing Implementation:
    - Added state machine parser in main.c for framed CDC packets
    - Packet format: [0xAA 0x55][2-byte length][payload][CRC-16]
    - Replaces simple length-prefix protocol with robust framing
    - Provides error detection via CRC-16 CCITT
    - Enables frame synchronization and recovery from corruption
    - Supports packets >64 bytes (CDC chunking)
    2. Protobuf Schema Update:
    - Renamed MouthpadUsb → MouthpadRelay for better clarity
    - Updated message types to reflect relay architecture
    - Changed message destinations and field names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
    [main.c]
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2025-10-13 Implement device info query in USB dongle firmware
    Handle DeviceInfoRead messages from app and respond with:
    - Advertised device name from BLE transport
    - Firmware version from DIS client
    - BLE MAC address
    - Vendor ID and Product ID from DIS PnP ID characteristic
    Chain DIS discovery after BAS completes to avoid GATT discovery
    conflicts. Query device info once when MouthPad connects.
    [main.c]
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2025-10-13 Fix USB dongle connection state reporting with proper state machine
    Implemented a comprehensive state machine for BLE central connection
    lifecycle to ensure accurate status reporting to the host application.
    Previously, the dongle would occasionally report DISCONNECTED during
    the connection transition instead of CONNECTING.
    - Added enum-based state machine (DISCONNECTED, SCANNING, CONNECTING, CONNECTED)
    - Replaced boolean `scanning_active` flag with proper state tracking
    - Set CONNECTING state immediately upon device match before any processing
    - Added state transition guards to prevent scan restart during connection
    - Made ble_central the single source of truth for connection stat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
    [main.c]
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2025-10-15 Limit buzzer initialization to XIAO boards only
    The passive buzzer is only available on XIAO boards when connected
    to the XIAO expansion board. Other boards (like nrf52840dongle) have
    PWM devices defined in devicetree but no physical buzzer hardware.
    - Use CONFIG_BOARD_XIAO_BLE preprocessor directive in buzzer_init()
    to skip initialization on non-XIAO boards
    - Update main.c to only log success when buzzer is actually available
    - Reduces unnecessary log output on boards without buzzer hardware
    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
    [main.c]
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2025-10-25 Unify bond reset logic across CDC, button, and protobuf
    Extract duplicated bond reset logic into shared perform_bond_reset()
    function to ensure consistent behavior across all three reset triggers:
    1. CDC 'reset' command
    2. Button long press
    3. Protobuf ClearBondsWrite command
    - Create main.h with perform_bond_reset() declaration
    - Implement perform_bond_reset() in main.c with full reset sequence:
    * Log bond info
    * Disconnect active BLE device (GAP disconnect + HID close fallback)
    * Wait 100ms for disconnect to complete
    * Clear all bonds from NVS (also clears device info)
    * Set LED state to scanning for visual feedback
    - Update button handler to call perform_bond_reset()
    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
    [main.c]
2025-10-25 Forward RSSI readings to relay protocol for status queries
    The relay protocol was not receiving RSSI updates from the BLE stack,
    so connection status queries always reported 0 dBm.
    - Add relay_protocol_update_rssi() function to update RSSI value
    - Call update_rssi() from ESP_GAP_BLE_READ_RSSI_COMPLETE_EVT handler
    - Reset RSSI to 0 when device disconnects
    - Remove TODO comment about tracking RSSI
    The RSSI timer already polls every 10 seconds via esp_ble_gap_read_rssi()
    and logs the value. Now it also forwards the value to the relay protocol
    so BleConnectionStatusRead queries return the current signal strength.
    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
    [main.c]
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2025-10-27 Guard NeoPixel power enable code to Adafruit Feather only
    The NeoPixel power enable code (P1.14) was running on all boards.
    Now it's properly wrapped in HAS_NEOPIXEL conditional to only execute
    on boards with NeoPixel support (Adafruit Feather nRF52840).
    This prevents unnecessary GPIO operations on other boards and ensures
    NeoPixel initialization only happens when the hardware is present.
    [leds.c]
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
